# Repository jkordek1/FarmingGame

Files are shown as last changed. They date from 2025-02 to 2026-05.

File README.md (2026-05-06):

# FarmingGame


[]()



## About
<p align="center">
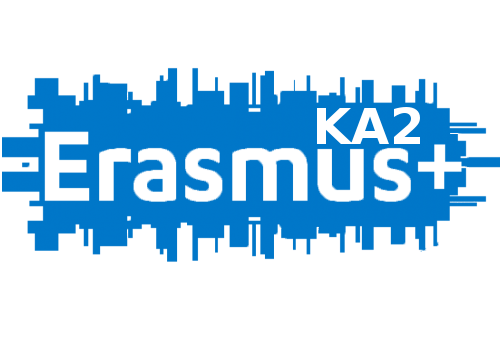
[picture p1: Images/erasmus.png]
  
</p>

This is an electronic board game about farming where 2-4 players compete to grow crops and score the most points. Players strategically plant crops with different growing times and point values, while dealing with unpredictable weather that affects crop growth. The game features three difficulty modes, each with unique weather mechanics and strategic depth.

**Key Features:**
- **Multiple difficulty modes**: Simple (beginner-friendly), Medium (balanced), and Advanced (strategic with crop-specific weather effects)
- **Dynamic weather system**: Weather drawn from a "bag" of 11 cards (4 Sunny, 3 Rain, 4 Drought) that refills when empty
- **Strategic depth**: Advanced mode includes stale crops (25% points if not harvested quickly) and planting limits (2 crops per turn)
- **Physical feedback**: LED ring shows field status, OLED displays for each player, central TFT screen with crop images
- **Sound and visual effects**: Weather animations, harvest celebrations, victory fanfare

## Project idea
The idea was to develop an electronic board game for 2-4 players that combines STEM with agriculture. It was funded by the Erasmus+ KA2 project [SEED2STEM: Planting the future of education](https://www.tvz.hr/introducing-seed2stem-planting-the-future-of-education/).

## How to Play

### Game Setup
1. **Power on** the device - "FARM GAME" logo appears
2. **Player 1** presses CONFIRM to start player selection (or hold BACK for settings)
3. **All players** press CONFIRM to join (2-4 players, 10-second window)
4. **Game begins** automatically when time expires or all slots filled

### Turn Structure
Each player's turn has three phases:

1. **Weather Phase**: Press CONFIRM to reveal weather → Check effects on your crops → Press CONFIRM to continue
2. **Field Management**: Navigate between fields (F1-F4) to harvest ready crops or plant new ones
3. **End Turn**: Navigate to "End Turn" and press CONFIRM twice (or hold FORWARD for quick skip)

### Controls
- **BACK/FORWARD**: Navigate left/right, decrease/increase values
- **CONFIRM**: Select, confirm actions
- **Hold FORWARD**: Quick jump to "End Turn" (1-second hold)

## Crops & Strategy

### Crop Information
| Crop | Turns to Grow | Simple Mode | Medium Mode | Advanced Mode |
|---|---|---|---|---|
| **Corn** 🌽 | 2 | 1 point | 2 points | 3 points |
| **Carrot** 🥕 | 3 | 4 points | 5 points | 6 points |
| **Tomato** 🍅 | 4 | 8 points | 9 points | 12 points |
| **Lettuce** 🥬 | 5 | 15 points | 16 points | 20 points |
| **Blueberry** 🫐 | 6 | 20 points | 25 points | 30 points |

### Game Modes

#### Simple Mode (Green) - Beginner Friendly
- **Weather effects**: Drought = no growth, Rain = 50% chance growth, Sun = normal growth
- **Strategy**: Focus on learning crop timing, weather is mostly unpredictable

#### Medium Mode (Yellow) - Balanced Challenge
- **Weather effects**: Drought = no growth, Rain = double growth, Sun = normal growth
- **Strategy**: Time plantings before rain for maximum benefit

#### Advanced Mode (Red) - Strategic Mastery
- **Crop-specific weather effects**: Each crop reacts differently to weather
  - **Drought**: Only corn survives (80% chance), others die
  - **Sun**: Corn & Tomato thrive (double growth), others normal
  - **Rain**: Carrot, Lettuce & Blueberry thrive (double growth), others normal
- **Stale crops**: Unharvested ready crops spoil and give only 25% points
- **Planting limit**: Maximum 2 crops per turn
- **Strategy**: Match crops to expected weather, harvest immediately when ready

### Weather System
Weather is drawn from a "bag" of 11 cards:
- **4 Sunny days** (36.4%)
- **3 Rainy days** (27.3%) 
- **4 Drought days** (36.4%)

When all cards are used, the bag refills and reshuffles. Players can track drawn weather to predict what's coming next!

## Project Status
- [x] Breadboard prototype
- [x] Schematic design
- [x] PCB design and manufacturing
- [x] Enclosure design and 3D printing
- [x] 3D CAD assembly and renders
- [x] Hardware assembly
- [x] Core game programming
- [x] **Game balancing completed** - All three difficulty modes fully implemented and balanced
- [x] **Weather system** - Sophisticated bag-based weather with crop-specific effects
- [x] **Advanced features** - Stale crops, planting limits, long-press shortcuts
- [x] **Audio/Visual polish** - Sound effects, animations, victory celebrations
- [x] **Documentation** - Complete rules, assembly instructions, cheat sheets
- [x] Final testing and optimization

## Current Game State
The game is **feature-complete and fully playable** with three balanced difficulty modes:
- **Simple Mode**: Perfect for beginners and casual play
- **Medium Mode**: Balanced challenge with predictable weather effects  
- **Advanced Mode**: Strategic depth with crop-weather matching, spoilage mechanics, and resource management

**Recent Major Updates:**
- Implemented crop-specific weather effects in Advanced mode
- Added stale crop mechanics (25% points penalty)
- Introduced per-turn planting limits (2 crops max in Advanced mode)
- Balanced weather bag system (4 Sun, 3 Rain, 4 Drought)
- Enhanced user interface with long-press shortcuts and improved text positioning
- Complete audio/visual feedback system

## Known Issues
- ~~Hardware is completely functional, software could use some extra work~~ ✅ **Resolved**
- ~~Due to ESP32 Neopixel library bug, the first WS2812B LED sometimes lights up green~~ ✅ **Fixed
- ~~Game balance needed adjustment~~ ✅ **Completed - all modes balanced**

**Current Status**: No major issues remaining. Game is stable and fully functional.

## Hardware & Display System

### Main Components
- **ESP32-S3 microcontroller** (Adafruit Feather ESP32-S3)
- **Central TFT display**: GC9A01 240x240 circular display showing crop images and game status
- **Player displays**: 4x SSD1306 128x64 OLED screens for individual player information
- **Status indicators**: WS2812B LED ring (16 LEDs, 4 per player) showing field status
- **Input system**: PCF8575 I/O expander with tactile buttons for each player
- **Audio feedback**: Buzzer for sound effects and music
- **Power management**: Optional MAX17048 battery fuel gauge
- **Connectivity**: Powered via USB-C

### Display System
- **Central TFT**: Shows active player (colored border), crop images, weather animations, victory screens
- **Individual OLEDs**: Personal scores, field information, menus, weather effects for each player
- **LED Ring**: Gray (empty field), colored (growing crop matching crop color), dark (player not active)
- **Audio**: Navigation beeps, weather sounds, harvest celebrations, victory fanfare

## 3D renders
Full1
Animation

## Images
IRL

## PCB
There is a donut-shaped circuit board containing a microcontroller, all SMD and THD components.

## Enclosure
The enclosure consists of three different sections: an upper orange section, a middle section and a lower section, both made of white PLA material. There are also three buttons in four different colors that are used for the menu controls. There is also a 3D printed part that represents four ground points for each player.

## Project folder structure
    ├── ...
    ├── Images                  # Images of the project
    ├── 3D models               # Enclosure model parts
    ├── KiCAD Files             # Main folder
    │   ├── FullPCB             # 3d models of components
    │       ├── BoardGame       # KiCAD project for main PCB
    └── ...

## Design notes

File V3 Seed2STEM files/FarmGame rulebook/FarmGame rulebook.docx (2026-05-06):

FarmGame rulebook

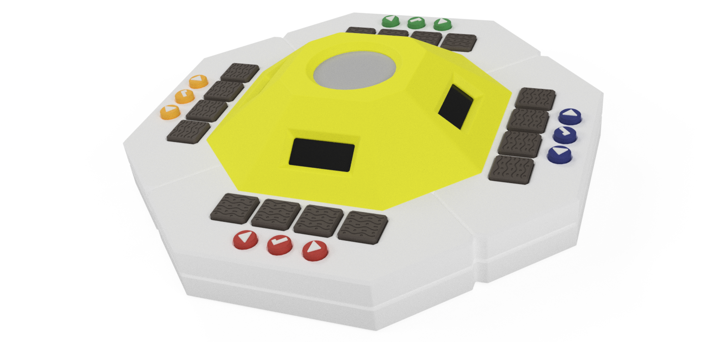
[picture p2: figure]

## Welcome to Farm Game!

Step into the boots of a farmer and compete with friends in this exciting agricultural challenge! You'll plant crops, manage unpredictable weather, and race to harvest at the perfect time to score the most points. Will you play it safe with quick-growing corn, or risk it all on precious blueberries?

## Getting Started

### Starting the Game

1. Turn on your device and watch the "FARM GAME" logo appear

2. Player 1 can either:

  - Press CONFIRM to go to player selection
  - Hold BACK for 2 seconds to access settings

### Player Selection (10 seconds)

- Each player presses CONFIRM to join the game
- You need at least 2 players to start (maximum 4)
- If there are not enough players, the game will continue waiting until more players join

## Controls and Display

### Your Controls

- BACK: Navigate left / Decrease value
- FORWARD: Navigate right / Increase value
- CONFIRM: Select / Confirm action

### Game Display

#### The Main Screen (Center)

Your central game view showing:

- Colored border: Shows whose turn it is
- Crop images: See what's growing in each field
- Field status: Empty fields, growing crops, or ready-to-harvest crops

#### Your Personal Screen (OLED)

Each player gets their own information display:

- Current score
- Field status and crop information
- Weather effects and menus
- Turn-specific information

#### Field Status Lights (LEDs)

16 colorful lights around the device showing everyone's field status:

- Gray lights: Empty fields
- Colored lights: Growing crops (each crop has its own color)
- Dark lights: Player not in the game

## Your Crops

Every crop has different growing times and point values. Some grow fast but give fewer points, others take longer but reward your patience!

Crop | Turns to Grow | Simple Mode | Medium Mode | Advanced Mode
Corn 🌽 | 2 turns | 1 point | 2 points | 3 points
Carrot 🥕 | 3 turns | 4 points | 5 points | 6 points
Tomato 🍅 | 4 turns | 8 points | 9 points | 12 points
Lettuce 🥬 | 5 turns | 15 points | 16 points | 20 points
Blueberry 🫐 | 6 turns | 20 points | 25 points | 30 points

### Crop Characteristics

- Corn: Quick and reliable, but modest points
- Carrot: Decent growing time with fair rewards
- Tomato: Takes patience but pays reasonably well
- Lettuce: Premium crop with good returns for the wait
- Blueberry: High maintenance and risky, but potentially the most rewarding!

## How to Play

### 1. Weather Phase ☀️🌧️🏜️

Every turn starts with checking the weather:

1. The active player presses CONFIRM to reveal the weather

2. Watch the weather animation on the main screen

3. Check your personal screen to see how the weather affects each of your crops:

  - Field number and crop name
  - Weather effect symbol (X, ?, +, ++, +++)

4. Press CONFIRM when ready to continue

Weather Types:

- Sunny ☀️: Generally good for crop growth
- Rain 🌧️: Some crops love it, others just get normal growth
- Drought 🏜️: Tough conditions - most crops struggle

### 2. Harvest and Plant Phase

Now you manage your 4 fields:

1. Use BACK/FORWARD to navigate between your fields (F1-F4) or "End Turn"

2. Quick tip: Hold FORWARD for 1 second to jump directly to "End Turn"

3. Press CONFIRM on any field to:

  - Empty field: Plant a new crop (if allowed)
  - Ready crop: Harvest and earn points
  - Growing crop: Nothing happens (you'll hear a beep)
  - End Turn: Confirm twice to finish your turn

When you harvest:

- Points appear in your player color
- Your score updates immediately
- The field becomes empty and ready for new crops

### 3. Planting Phase (when you select an empty field)

1. Browse available crops with BACK/FORWARD

2. Your screen shows the crop name, main screen shows turns and points

3. Press CONFIRM to plant the selected crop

4. Return to field management

### 4. End of Turn

- Weather effects are applied to all your growing crops
- Next player takes their turn
- Game continues until all rounds are complete

## Game Modes

Choose your difficulty level! Each mode offers different weather mechanics and point values.

### SIMPLE Mode - "Learning the Basics"

Weather Effects:

- Drought: No growth for any crops
- Rain: 50% chance each crop will grow (random)
- Sun: Normal growth for all crops

Best for: New players learning the game. Weather is unpredictable, so focus on understanding crop timing.

### MEDIUM Mode - "Balanced Challenge"

Weather Effects:

- Drought: No growth for any crops
- Rain: Double growth for all crops (-2 turns)
- Sun: Normal growth for all crops (-1 turn)

Best for: Players who want predictable weather patterns. Rain becomes very powerful for everyone.

### ADVANCED Mode - "Strategic Farming"

Weather Effects:
Each crop reacts differently to weather conditions:

Weather | Corn 🌽 | Carrot 🥕 | Tomato 🍅 | Lettuce 🥬 | Blueberry 🫐
Drought | 80% chance normal growth | No growth | No growth | No growth | No growth
Sun | Double growth (-2 turns) | Normal growth | Double growth (-2 turns) | Normal growth | Normal growth
Rain | Normal growth | Double growth (-2 turns) | Normal growth | Double growth (-2 turns) | Double growth (-2 turns)

Weather Effect Symbols:

- X = No growth / Stale crop
- ? = Chance-based growth (80% for corn in drought)
- + = Normal growth (-1 turn)
- ++ = Double growth (-2 turns)

Advanced Mode Special Rules:

Stale Crops:

- Crops left unharvested too long will spoil and lose value
- Stale crops show "STALE" in red and give only 25% points
- You must harvest quickly or watch your crops deteriorate!

Planting Limit:

- You can only plant 2 crops per turn (not total - per turn!)
- Your screen shows "Planted:X/2" to track your progress
- Empty fields show "X" when you've reached your limit
- Choose your plantings wisely each turn!

Best for: Experienced players who enjoy strategic depth. Match crops to expected weather, harvest quickly to avoid spoilage, and plan your limited plantings carefully.

## Settings Menu

### Accessing Settings

From the start screen, Player 1 holds BACK for 2 seconds to enter the settings menu.

### Available Settings

#### 1. LED Brightness

- Options: 0%, 25%, 50%, 75%, 100%
- Default: 50%
- What it does: Adjusts how bright the status lights shine
- The lights turn on when you enter this setting

#### 2. Number of Rounds

- Options: 5, 10, 15, or 20 rounds
- Default: 10 rounds
- What it does: Sets how many turns each player gets

#### 3. Menu Sounds

- Options: ON / OFF
- Default: ON
- What it does: Toggle the helpful beeps and navigation sounds

#### 4. Battery Info

- Display: Shows battery voltage and remaining power
- What it does: Monitors your device's power supply (if battery sensor is connected)
- Color coding: Green (good), Orange (low), Red (very low)
- Note: Information only - you can't change this setting

#### 5. Weather System

- Options: SIMPLE / MEDIUM / ADVANCED
- Default: SIMPLE
- What it does: Changes how weather affects crops and determines point values

#### 6. Exit Settings

- Action: Saves all settings and returns to player selection
- Your settings are remembered when you power off the device

### Using Settings

- BACK/FORWARD: Navigate between settings
- CONFIRM: Enter adjustment mode
- While adjusting:
  - BACK/FORWARD: Change the value
  - CONFIRM: Save and exit adjustment mode

## Winning the Game

### Scoring

Your score increases each time you harvest a ready crop. Point values depend on the crop type and which game mode you're playing (see the crop table above).

### Game End

- The game ends after everyone completes their set number of rounds
- Victory music plays (a triumphant C-E-G-C fanfare)
- The winner's status lights pulse three times in celebration
- The player with the highest score wins
- If there's a tie: Multiple winners share the victory with "TIE!" displayed

Victory Screen:

- Main Screen: Shows the winner's name with their color, plus complete rankings of all players
- Winner's Screen:
  - Displays "YOU WON!" or "TIED!" in the center
  - Shows "Press CONFIRM" to start a new game
  - Only winners can start the next game
- Other Players' Screens:
  - Shows their final ranking and total score
  - Must wait for the winner to decide on starting a new game

## Tips & Strategy

### General Strategy

1. Quick crops (like corn) are safe bets but give fewer points

2. Slow crops (like blueberries) are risky investments but can pay off big

3. Keep an eye on weather patterns - they come from a limited "bag" of possibilities

4. Don't put all your eggs in one basket - diversify your fields

### Understanding Weather Patterns

Weather isn't completely random! It comes from a "weather bag" containing:

- 4 Sunny days
- 3 Rainy days
- 4 Drought days

Once all 11 weather cards are used, the bag refills. Smart players track what's been drawn to predict what's coming next!

### Mode-Specific Tips

Simple Mode:

- Focus on learning crop timing rather than weather prediction
- Plant a mix of fast and slow crops to spread your risk
- Weather is mostly unpredictable, so don't rely on it too much

Medium Mode:

- Plant slower crops before expected rain for maximum benefit
- Rain helps everyone equally, so timing is everything
- Drought is your enemy - harvest quickly when you see it coming

Advanced Mode:

- Match crops to weather:
  - Plant corn before sun or drought (it's tough and loves sun)
  - Plant tomatoes before sunny weather
  - Plant carrots and lettuce before rain
  - Plant blueberries before rain (they love it - 30 points!)
- Harvest immediately when crops are ready - spoilage costs you 75% of your points!
- Plan your 2 plantings per turn carefully - prioritize high-value crops
- Track the weather bag - with 4 droughts, 3 rains, and 4 sunny days, drought is most common

### Field Management

- Keep crops at different growth stages so you always have something ready
- Never leave all fields empty (unless you've hit your planting limit in Advanced mode)
- In Advanced mode, sometimes harvesting is more important than planting
- Time-saving tip: Hold FORWARD for 1 second to quickly jump to "End Turn"

## Player Colors

- Player 1: Red
- Player 2: Yellow
- Player 3: Green
- Player 4: Blue

## Ready to Play?

Now you know everything you need to become a farming champion! Start with Simple mode to learn the basics, then challenge yourself with Medium and Advanced modes.

Whether you're growing reliable corn or precious blueberries, every choice matters. Good luck, and may the best farmer win! 🌾

## Technical Information

### Hardware Requirements

- ESP32-S3 microcontroller
- GC9A01 240x240 TFT display
- 4x SSD1306 128x64 OLED displays
- WS2812B LED ring (16 LEDs)
- PCF8575 I/O expander for buttons
- MAX17048 battery fuel gauge (optional)
- Buzzer for sound effects

### Display Layouts

TFT Screen:

- Colored ring showing active player
- Center area: crop images, field status, weather
- Score display during status updates

OLED Screens:

- Player-specific information
- Field selection menus
- Crop selection menus
- Weather effects summary
- Turn status

## Troubleshooting

### Game Won't Start

- Ensure at least 2 players press CONFIRM during player selection
- Check that all displays are connected

### No Sound

- Check Menu Sounds setting (may be OFF)
- Verify buzzer connection

### Battery Shows "Sensor not found"

- MAX17048 sensor not detected or not connected
- Game still playable without battery monitoring

### LEDs Not Working

- Check LED Brightness setting (may be 0%)
- Verify LED ring connection

## Credits

Farm Game - A competitive multiplayer farming experience with strategic weather mechanics and crop management.

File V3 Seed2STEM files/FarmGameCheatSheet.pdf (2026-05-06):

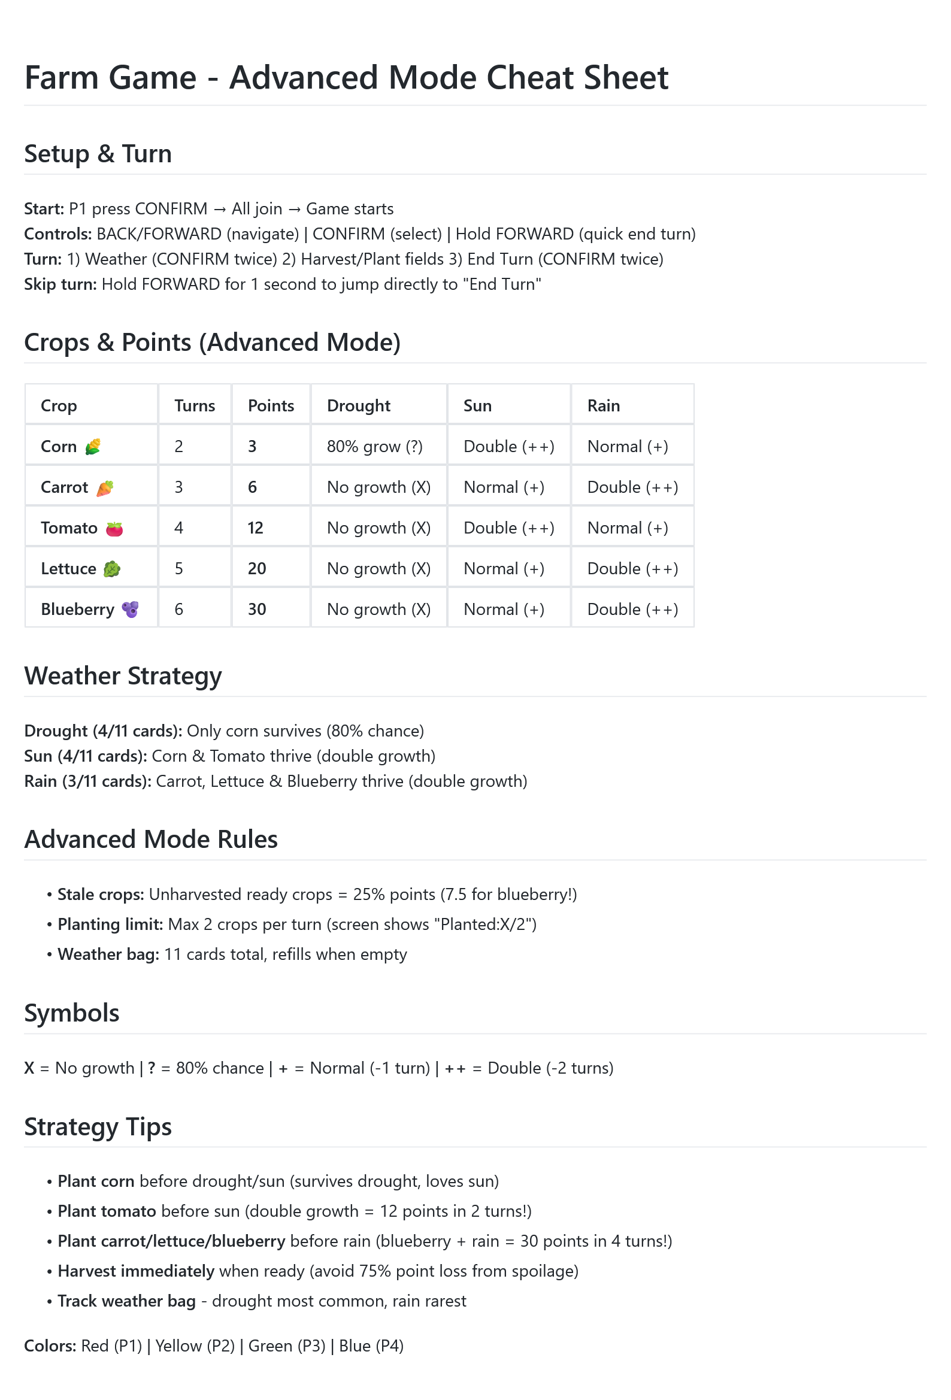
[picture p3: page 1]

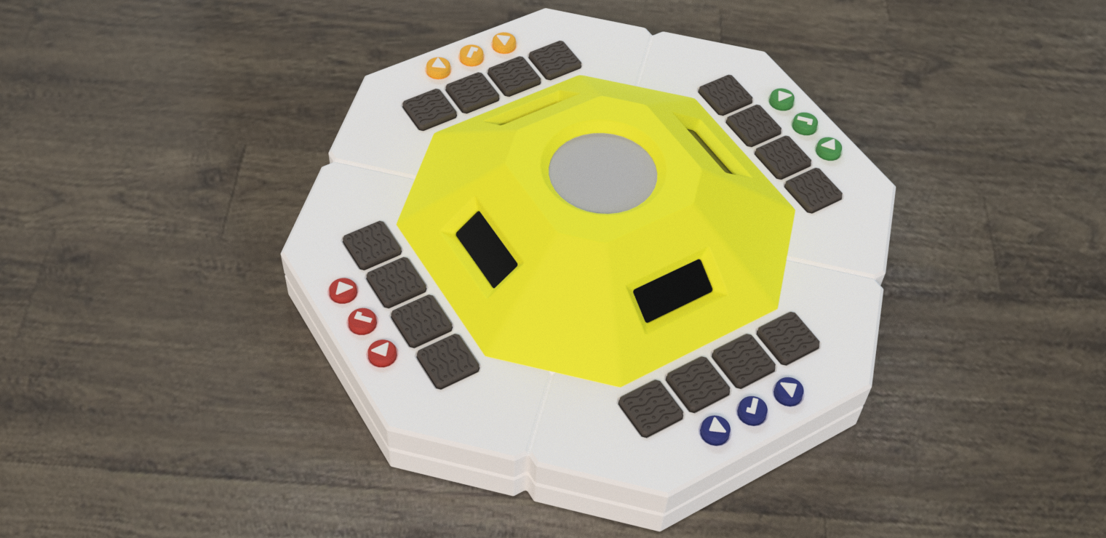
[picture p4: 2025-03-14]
Images/Full1.png

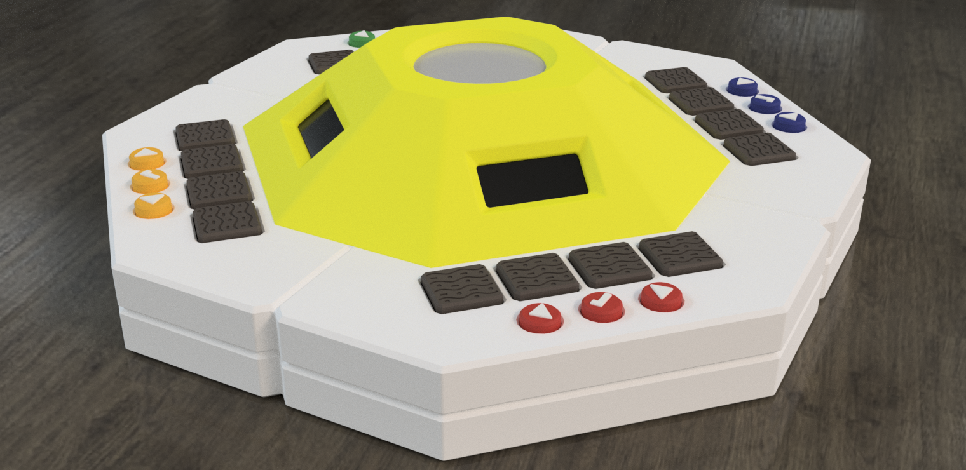
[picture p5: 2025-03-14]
Images/Full2.png

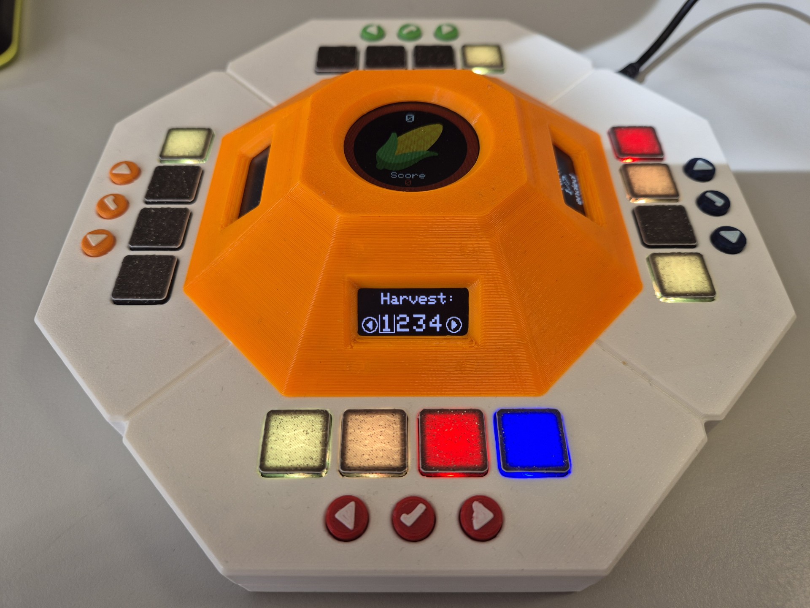
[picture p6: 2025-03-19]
Images/IRL.jpg

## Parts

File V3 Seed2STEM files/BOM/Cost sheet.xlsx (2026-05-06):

Name | # of pieces per device | # of pieces for 10 devices | Cost for 10 devices [€] | Supplier
PCB with pre-assembled SMT components | 1 | 10 | 70.00 | JLCPCB
Power switch | 1 | 10 | 15.00 | Digikey (https://www.digikey.com/en/products/detail/zf-electronics/PRK22J5BBBNN/1083857)
Speaker | 1 | 10 | 2.10 | TME (https://www.tme.eu/hr/en/details/ld-bzen-1205/electromagnetic-sounders-w-o-generator/loudity/)
Port expander | 1 | 10 | 50.00 | Adafruit (https://www.adafruit.com/product/5611)
Battery | 1 | 10 | 75.00 | soldered (https://soldered.com/products/li-ion-battery-1200mah-3-7v?variant=62540928516445)
ESP32 microcontroller | 1 | 10 | 150.00 | Adafruit (https://www.adafruit.com/product/5885)
Push button | 12 | 120 | 7.94 | TME (https://www.tme.eu/hr/en/details/tact-64k-f/microswitches-tact/ninigi/)
Pin strip | 1 | 10 | 1.34 | TME (https://www.tme.eu/hr/en/details/ph1rb-40-ua/pin-headers/adam-tech/)
OLED cables 10cm | 5 | 50 | 47.50 | soldered (https://soldered.com/product/easyc-cable/)
GC9A01 cables | 8 | 80 | 7.00 | soldered (https://soldered.com/hr/proizvod/set-kablica-zensko-zenski-40-komada/)
M3 inserts | 16 | 160 | 27.52 | TME (https://www.tme.eu/hr/en/details/kvt-117m3/threaded-insertions/tappex/117m3/)
M2.5 inserts | 36 | 360 | 54.00 | TME (https://www.tme.eu/hr/en/details/kvt-002m2/threaded-insertions/tappex/002m2/)
M3 screws | 16 | 160 | 4.21 | TME (https://www.tme.eu/hr/en/details/b3x8_bn16/bolts/bossard/1017985/)
M2.5 screws | 36 | 360 | 10.33 | TME (https://www.tme.eu/hr/en/details/b2x5_bn2724/screws/bossard/5001676/)
GC9A01 display | 1 | 10 | 15.60 | aliexpress (https://www.aliexpress.com/item/1005007702290129.html?curPageLogUid=5H3M1Fq1tWO2)
OLED displays | 4 | 40 | 398.00 | soldered (https://soldered.com/product/display-oled-i2c-white-0-96-ssd1306/)
Bottom 3D printed part | 1 | 10 | 0.00 | -
Middle 3D printed part | 1 | 10 | 0.00 | -
Top 3D printed part | 1 | 10 | 0.00 | -
Field 3D printed part | 4 | 40 | 0.00 | -
Left/right button 3D printed part | 8 | 80 | 0.00 | -
Rubber feet | 8 | 80 | 0.00
Confirm 3D printed part | 4 | 40 | 0.00 | -
 |  |  | 935.54
 |  | Cost per device: | 93.5542 | (3D printed parts not included)

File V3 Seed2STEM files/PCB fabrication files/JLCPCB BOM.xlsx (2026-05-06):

Comment | Designator | Quantity | Footprint | LCSC Part #
WS2812B | D1, D10, D11, D12, D13, D14, D15, D16, D2, D3, D4, D5, D6, D7, D8, D9 | 16 | SMD5050-4P | C2874885
Resistor 220R | R1 | 1 | 0805 | C17557
Resistor 10k | R2, R13, R14, R15, R10, R11, R12, R7, R8, R9, R16, R17, R18 | 13 | 0805 | C17414
SMD Connector | J2 | 1 | SMD,P=1mm | C371510
Resistor 680R | R3, R6 | 2 | 0805 | C17798
Transistor NPN | Q1, Q2 | 2 | SOT-23 | C8512
MOSFET | Q3 | 1 | SOT-23 | C15127

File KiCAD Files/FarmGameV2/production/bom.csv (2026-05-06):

Designator | Footprint | Quantity | Value | LCSC Part #
BZ1 | Buzzer_TDK_PS1240P02BT_D12.2mm_H6.5mm | 1 | Buzzer
D1, D10, D11, D12, D13, D14, D15, D16, D2, D3, D4, D5, D6, D7, D8, D9 | LED_WS2812B_PLCC4_5.0x5.0mm_P3.2mm | 16 | WS2812B
J2 | JST_SH_SM04B-SRSS-TB_1x04-1MP_P1.00mm | 1 | OLED3&4
J5 | PinHeader_1x08_P2.54mm_Horizontal | 1 | Conn_01x08
Q1, Q2 | SOT-23 | 2 | MMBT2222A
Q3 | SOT-23 | 1 | AO3401A
R1 | 0805 | 1 | 220R
R10, R11, R12, R13, R14, R15, R16, R17, R18, R2, R7, R8, R9 | 0805 | 13 | 10k
R3, R6 | 0805 | 2 | 680R
SW1, SW10, SW11, SW12, SW2, SW3, SW4, SW5, SW6, SW7, SW8, SW9 | SW_PUSH_6mm | 12 | SW_Push_Dual
SW13 | Switch | 1 | POWER
U2 | ESP32-S3 | 1 | ~
U3 | PCF8575 | 1 | PCF8575

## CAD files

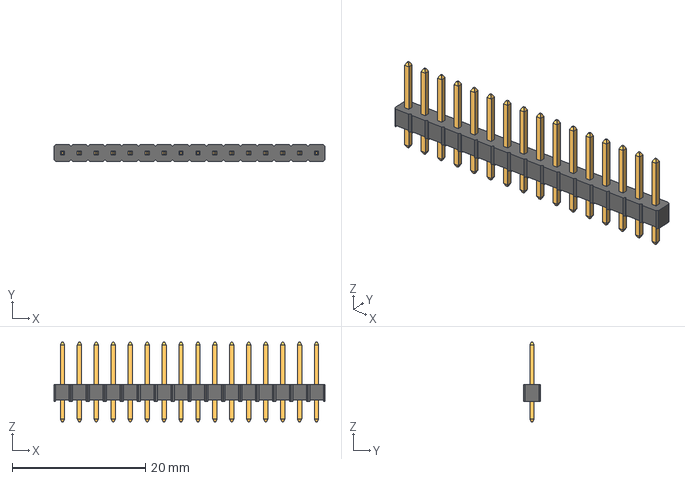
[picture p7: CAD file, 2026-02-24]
KiCAD Files/FarmGameV2/3DMODELS/16-Pin Header - Male - 2.54mm.step
40.6 x 2.54 x 11.9 mm

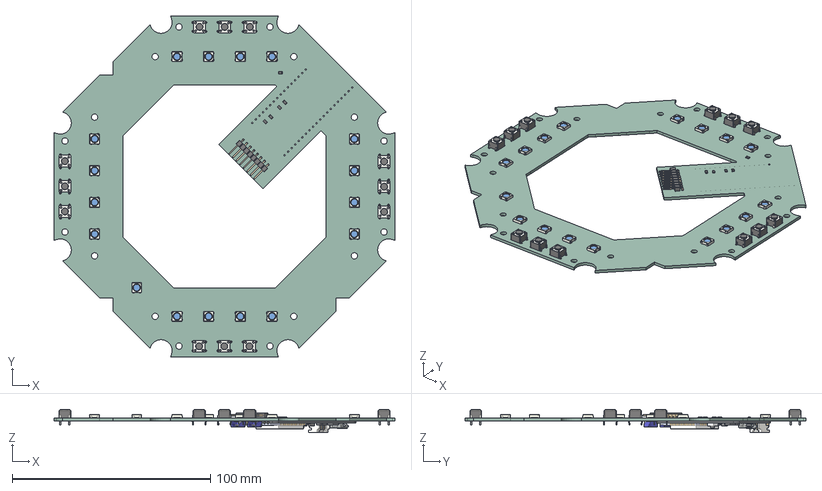
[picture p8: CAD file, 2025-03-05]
KiCAD Files/FarmGameV2/FarmGameV2.step
172.1 x 172.1 x 11.8 mm
LED_WS2812B_PLCC4_5.0x5.0mm_P3.2mm x 17
R_0805_2012Metric x 5
SW_PUSH_6mm x 12
PinHeader_1x08_P2.54mm_Horizontal
ESP32-WROVER v1
shield
JST PH M2P SMD v1
SM04B-SRSS-TB x 2
FullPCB_PCB

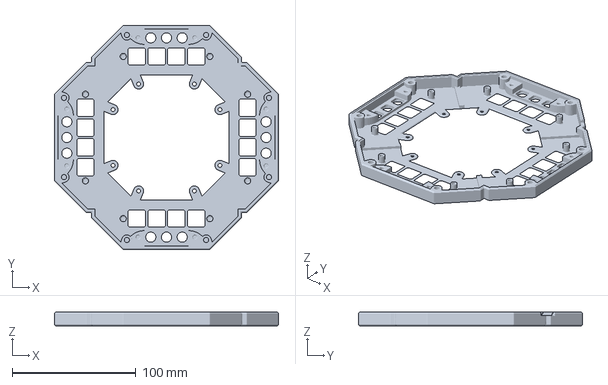
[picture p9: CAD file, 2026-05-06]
V3 Seed2STEM files/Enclosure 3D models/3MF/MiddleBodyPart.3mf
181.1 x 181.1 x 11.0 mm

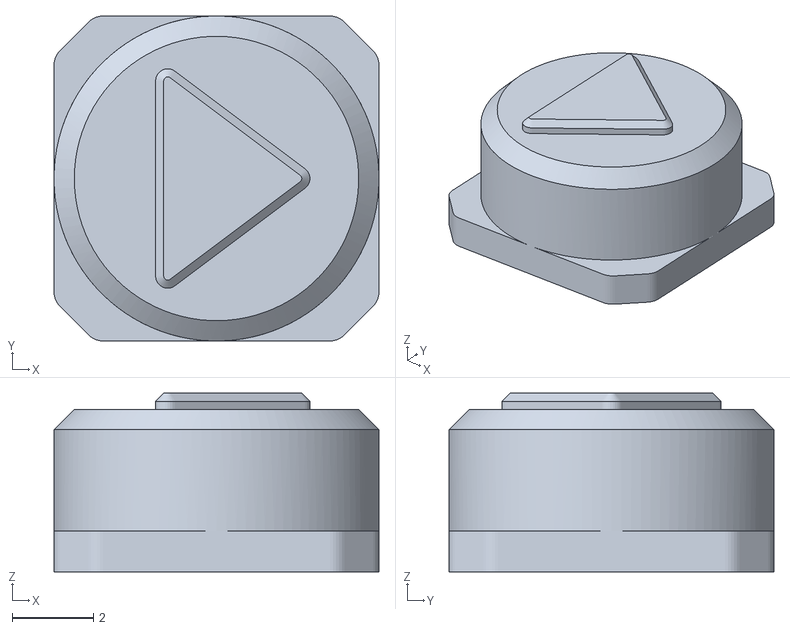
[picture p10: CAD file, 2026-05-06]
V3 Seed2STEM files/Enclosure 3D models/STL/Button - LeftRight.stl
8.00 x 8.00 x 4.40

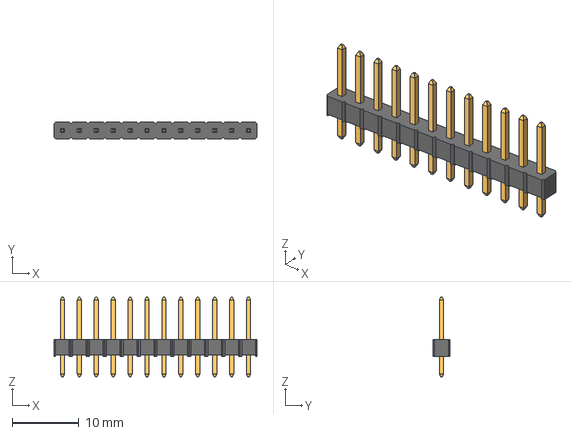
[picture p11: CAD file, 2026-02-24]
KiCAD Files/FarmGameV2/3DMODELS/12-Pin Header - Male - 2.54mm.step
30.5 x 2.54 x 11.9 mm

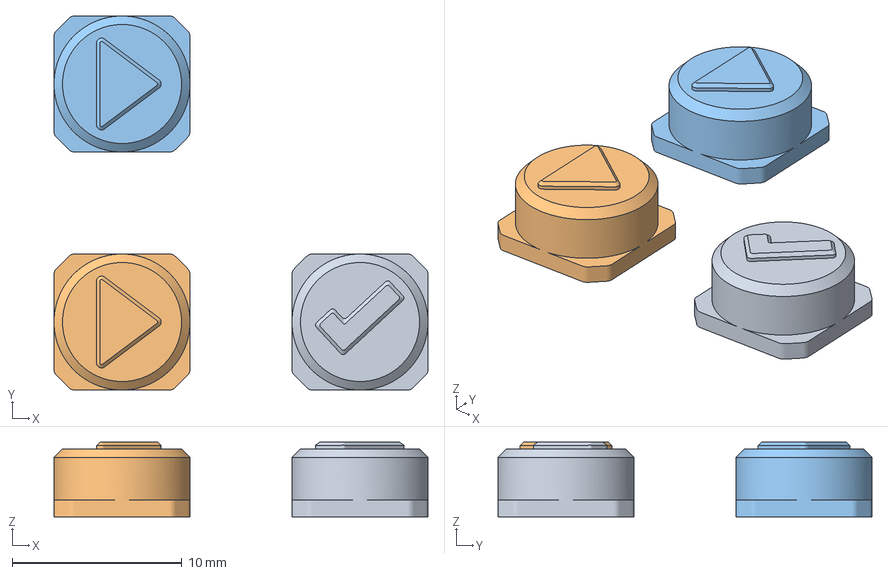
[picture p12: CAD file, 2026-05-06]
V3 Seed2STEM files/Enclosure 3D models/3MF/Buttons.3mf
22.0 x 22.0 x 4.40 mm
Button - Confirm.stl
Button - LeftRight.stl x 2

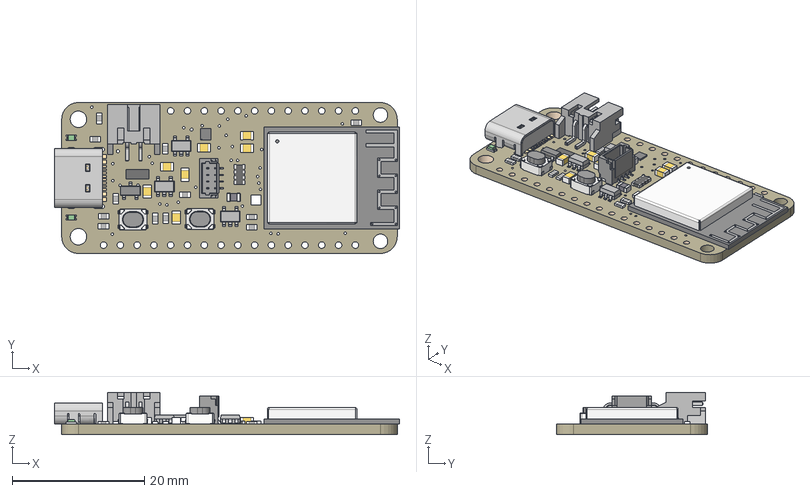
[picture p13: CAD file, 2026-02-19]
KiCAD Files/FarmGameV2/3DMODELS/Feather ESP32-S3.step
52.2 x 22.9 x 6.37 mm
Board
10uF x 7
AP2112/RT9080-3.3 x 3
MBR540
JSTPH
RED x 2
1uF x 12
KMR2 x 2
DMG3415U
USB C
ESP32-S3-MINI-1
LC709203F/MH
JST SH
WS2812B_SK6805_1515
10uF_1
10K

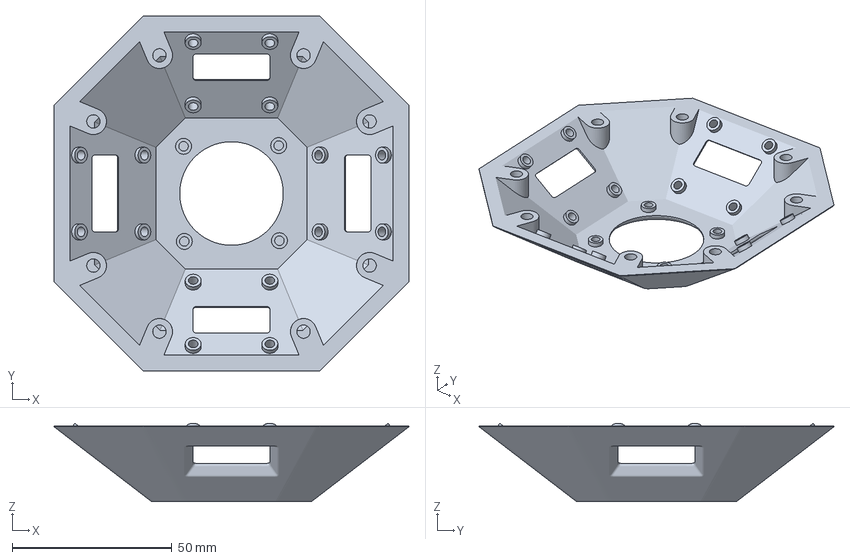
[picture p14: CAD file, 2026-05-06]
V3 Seed2STEM files/Enclosure 3D models/3MF/UpperBodyPart.3mf
111.1 x 111.1 x 24.5 mm

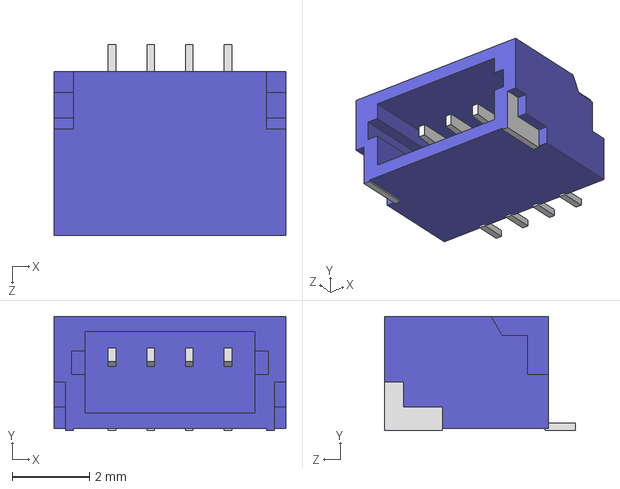
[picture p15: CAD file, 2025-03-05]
KiCAD Files/FarmGameV2/3DMODELS/SM04B-SRSS-TB.STEP
6.00 x 2.96 x 4.95 mm

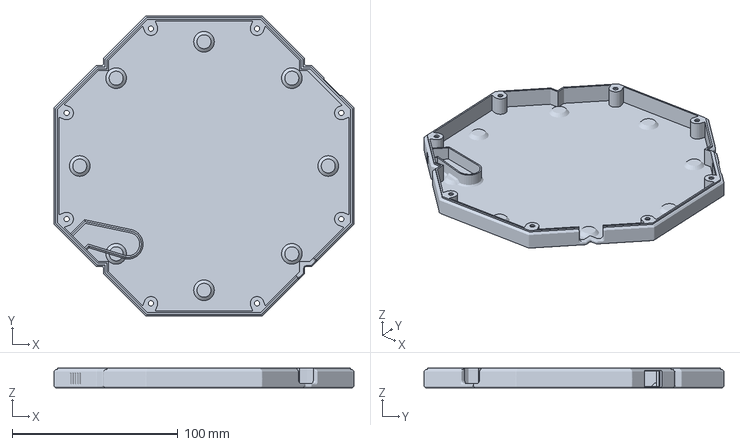
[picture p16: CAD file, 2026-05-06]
V3 Seed2STEM files/Enclosure 3D models/3MF/BottomBodyPart.3mf
181.1 x 181.1 x 12.0 mm

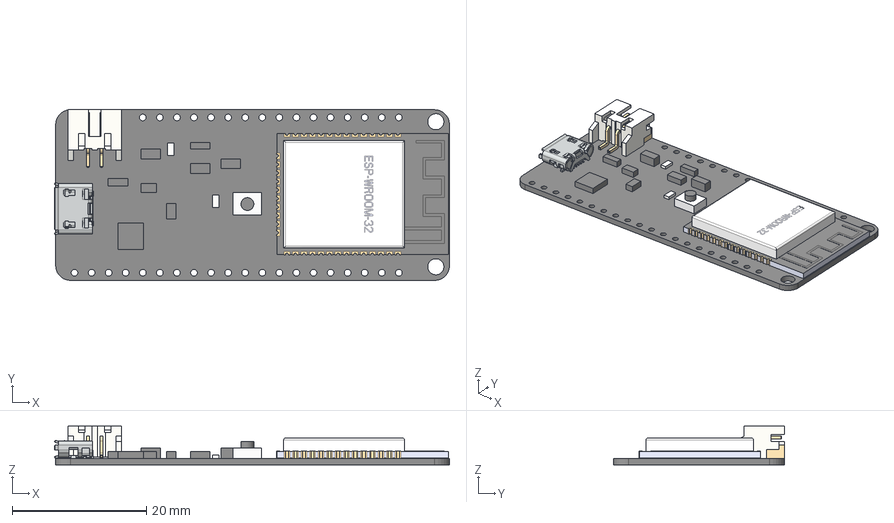
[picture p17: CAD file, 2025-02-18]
KiCAD Files/FarmGameV2/3DMODELS/Lolin32+V1.0.0 v2.step
58.8 x 25.4 x 5.80 mm
ESP32-WROVER
shield
JST PH M2P SMD

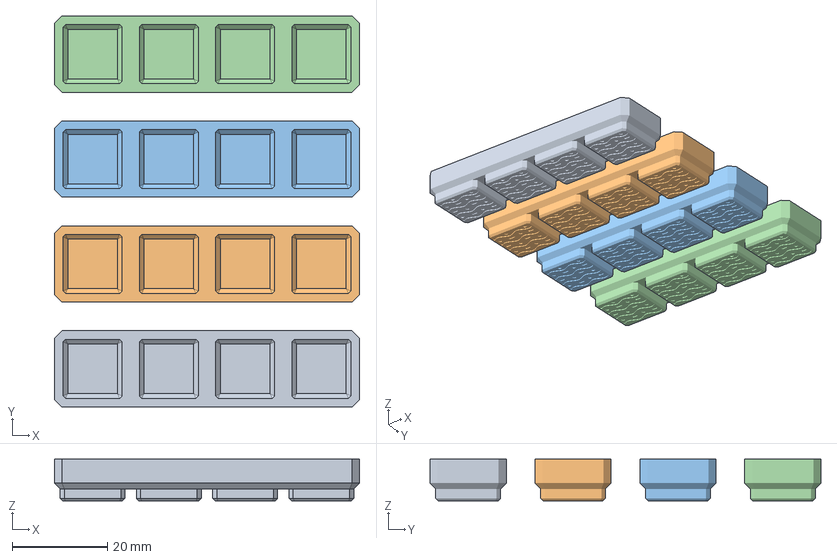
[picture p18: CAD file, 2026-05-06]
V3 Seed2STEM files/Enclosure 3D models/3MF/Field.3mf
64.0 x 82.0 x 8.75 mm
Field.stl x 4

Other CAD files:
V3 Seed2STEM files/Enclosure 3D models/STL/Button - Confirm.stl
V3 Seed2STEM files/Enclosure 3D models/STL/BottomBodyPart.stl
V3 Seed2STEM files/Enclosure 3D models/STL/Field.stl
V3 Seed2STEM files/Enclosure 3D models/STL/MiddleBodyPart.stl
V3 Seed2STEM files/Enclosure 3D models/STL/UpperBodyPart.stl

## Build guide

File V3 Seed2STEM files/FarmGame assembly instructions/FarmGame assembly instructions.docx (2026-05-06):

FarmGame assembly instructions

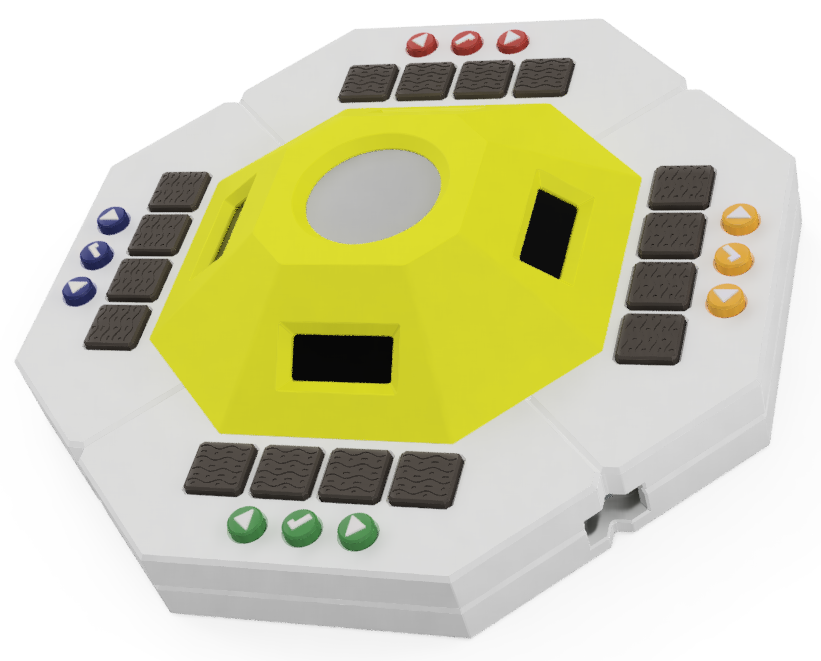
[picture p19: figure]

1. Ordering the printed circuit board (PCB) from manufacturer

Every FarmGame device has single PCB which contains most of the electronic components. Surface mount (SMT) components are hard to solder so it is required for the manufacturer to assemble the PCBs. Luckily, JLCPCB is a fast, reliable and cheap manufacturer which can do just that but we are not limited to their service, any other manufacturer will do since there are production files available. You can find the gerber files, BOM (Bill of materials) and CPL (Component placement list) in the PCB fabrication folder.

That said, go to jlcpcb.com and create a new quote. Click „add a gerber file“ and select the gerber.zip. Choose PCB quantity 5. On the bottom of the page, enable „PCB assembly“ and select Standard PCBA Type. This feature will enable you to assemble both PCB sides so select the Both Sides as Assembly Side.

Click Next and on the next screen you will see Top and Bottom sides of PCB. Click Next again. Now you will need to upload the BOM and CPL files from the PCB fabrication folder. After that click Process BOM&CPL. Check for errors and click Next. Check for component placement and orientation and click Next to proceed with the quote and finish with the payment process.

2. Ordering the rest of the electronical and mechanical components

In the BOM folder you can find the Cost Sheet with complete list of the all parts needed for the FarmGame. The last column contains supplier names and direct links to the catalog on their websites. Choose the required quantity and order all of them.

3. 3D printing the parts of enclosure

There are multiple 3D printed parts needed in order to assemble the FarmGame. All the files are available in the 3MF folder. Open the files using your printers slicing software. Here are some guidelines for 3D printing the models for each part of the FarmGame:

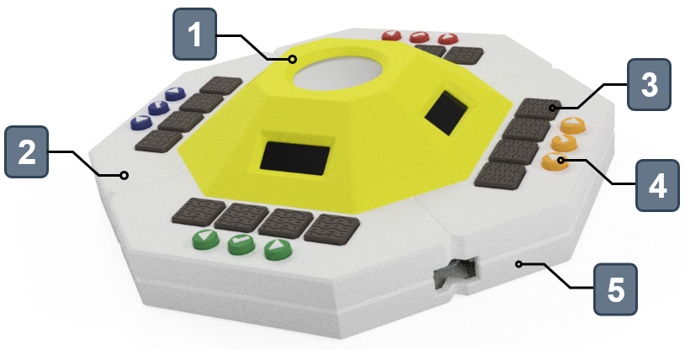
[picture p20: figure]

1. Upper body part
- Use yellow PLA material
- Use default settings in .3mf file
- Print on textured plate
- Remove support material
2. Middle body part
- Use white PLA material
- Use default settings in .3mf file
- Print on textured plate
3. Field
- Start printing with GalaxyBlack or similiar PLA material
- When printer pauses for color change use white PLA material
- End print with the same material which you started with
- Use default settings in .3mf file
- Print on textured plate
- Remove support material
4. Buttons
- Print 4 different sets of buttons using different colored (red, blue, yellow and green) PLA materials
- When printer pauses for color change use white PLA material
- Print on smooth plate
5. Bottom body part
- Use white PLA material
- Use default settings in .3mf file
- Print on textured plate
- Remove support material
4. Soldering

Tools and parts:

- 1x PCB with presoldered SMD components
- 12x Push buttons
- 1x Pin strip
- 1x ESP32 microcontroller
- 1x Speaker
- 1x Port expander
- Soldering iron

This part requires some soldering skills in order to solder the push buttons, pin strip and ESP32 microcontroller. Pay attention to which side you need to solder the components on. The push buttons (SW1 – SW12) and pin strip (J5) need to be placed from top side (soldered from the bottom side) – it's the side where the LEDs are soldered on.

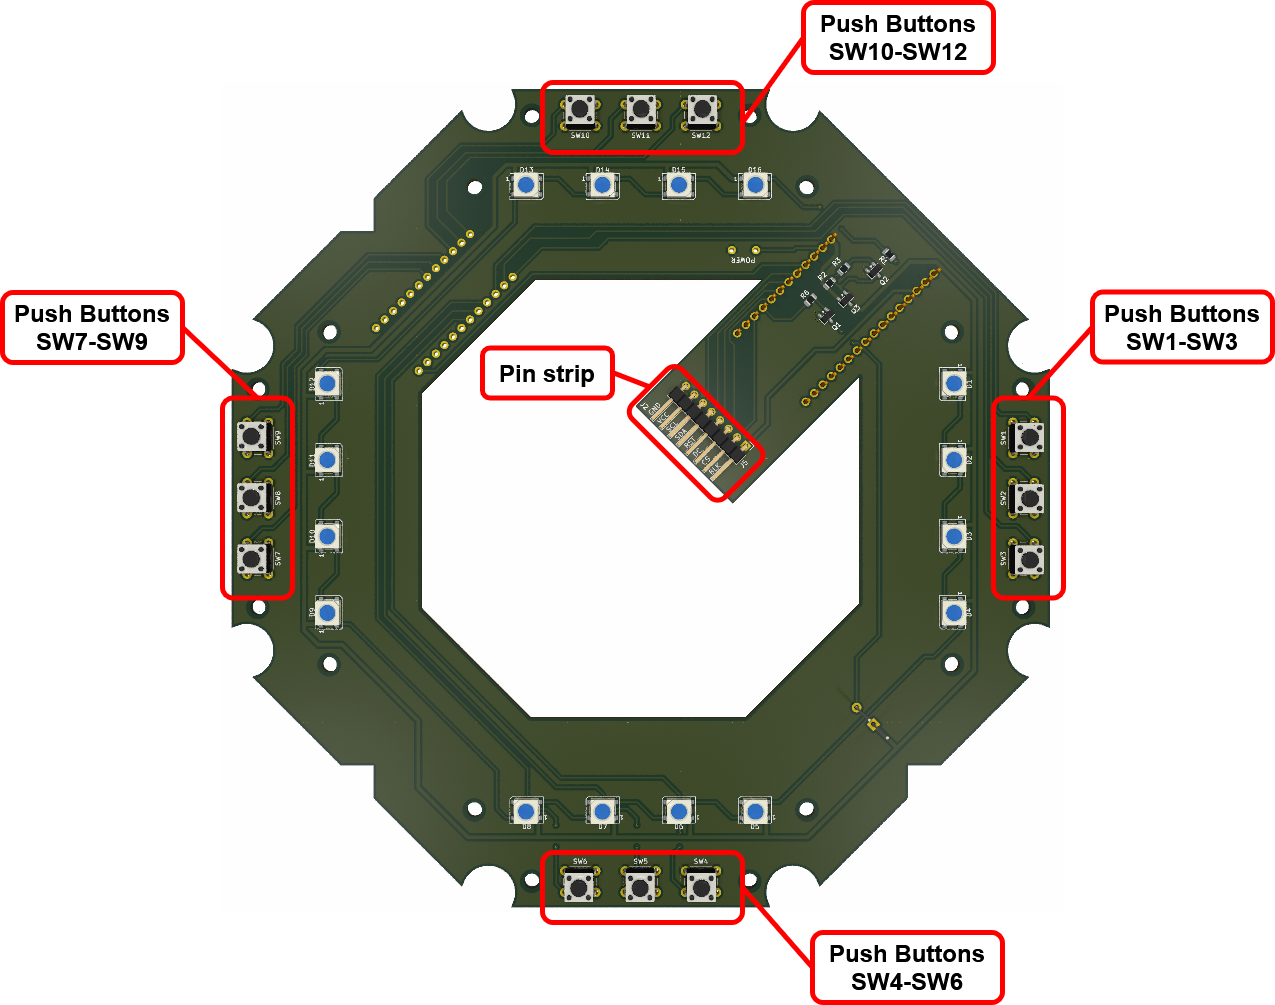
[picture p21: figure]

The ESP32 microcontroller, speaker, and port expander must be placed and soldered on the bottom side of the board, the same side as connector J2. The port expander must be oriented in a way that its VIN pin aligns with the hole marked by the white dot.

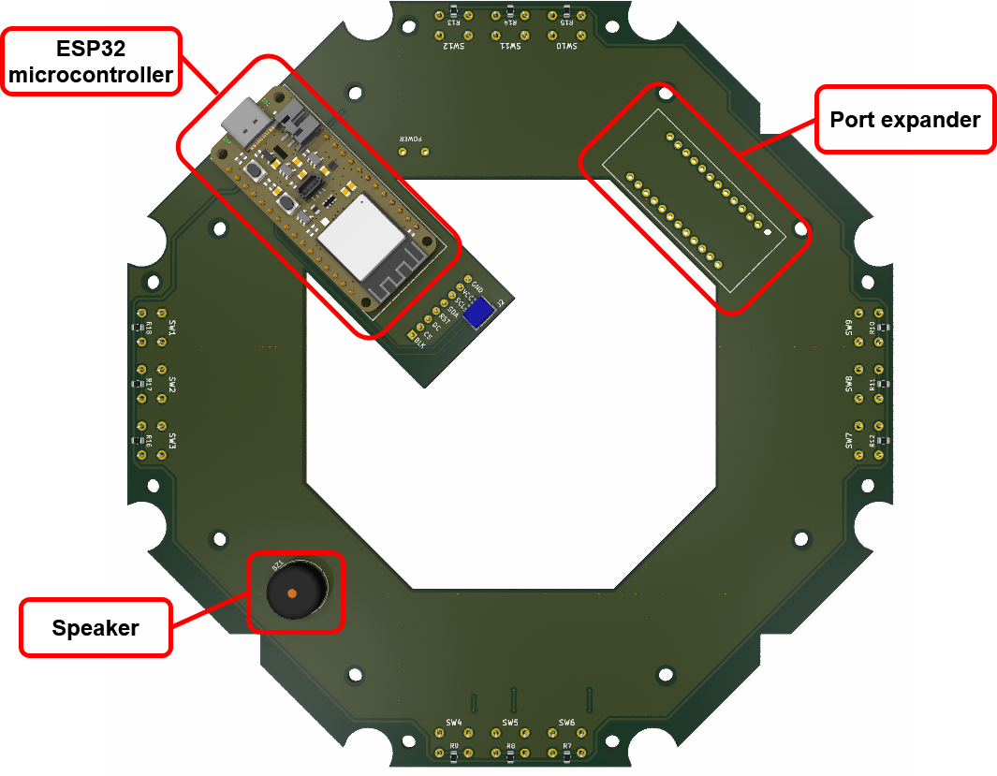
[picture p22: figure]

5. Installing brass threaded inserts

Tools and parts:

- 36x M2 threaded inserts
- 16x M3 threaded inserts
- Upper body part
- Middle body part
- Soldering iron

Before using screws, the brass threaded inserts must be installed. This is done using the soldering iron, set to a maximum tip temperature of 200 °C. Two sizes of brass inserts are required: M2 and M3. The size difference is obvious—the smaller inserts are M2, and the larger ones are M3. Be careful not to mix them up.

The Upper body part requires 20 M2 inserts marked with blue and 8 M3 inserts marked with red color:

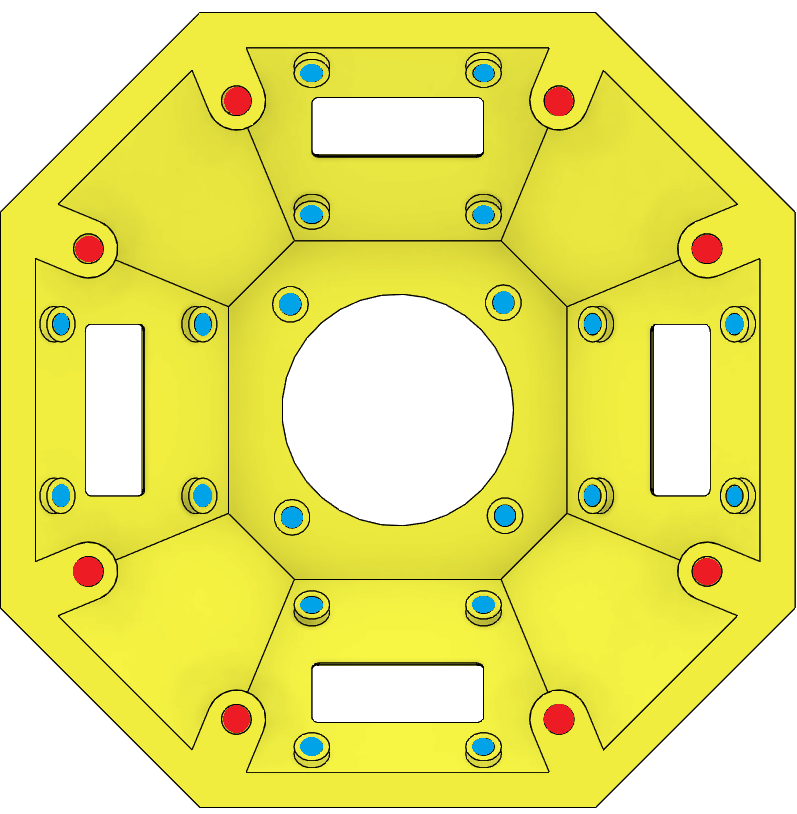
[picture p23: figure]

The Middle body part needs 16 M2 inserts marked with blue and 8 M3 inserts marked with red color pressed in using soldering iron:

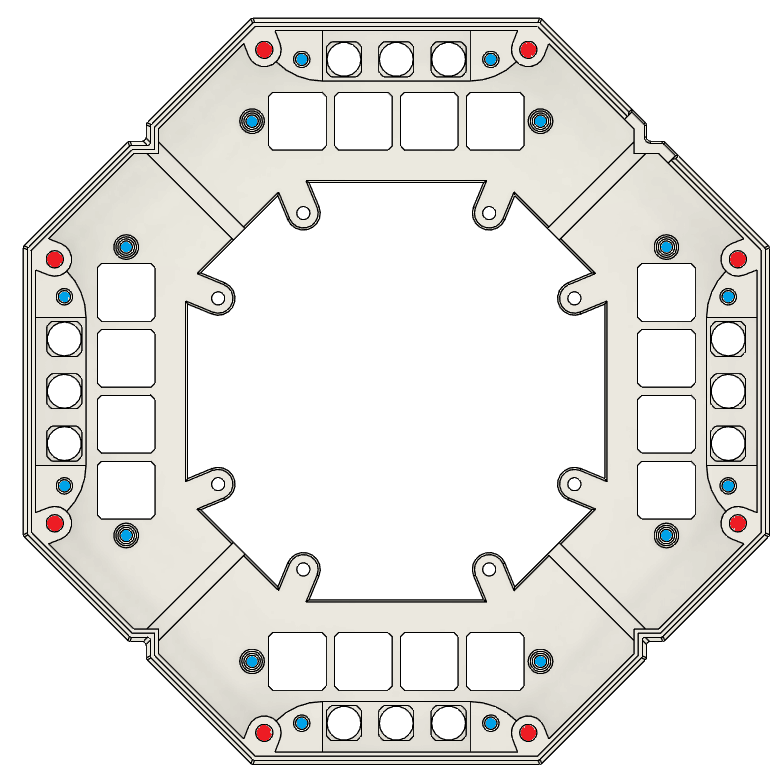
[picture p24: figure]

6. OLED display jumpers

Parts and tools:

- 2x OLED display
- Soldering iron

Every FarmGame device uses four different OLED displays. To get them to work properly, on two of them the jumper marked as JP6 needs to be shorted using the soldering iron. It should look something like this (notice the yellow arrow indicating the jumper):

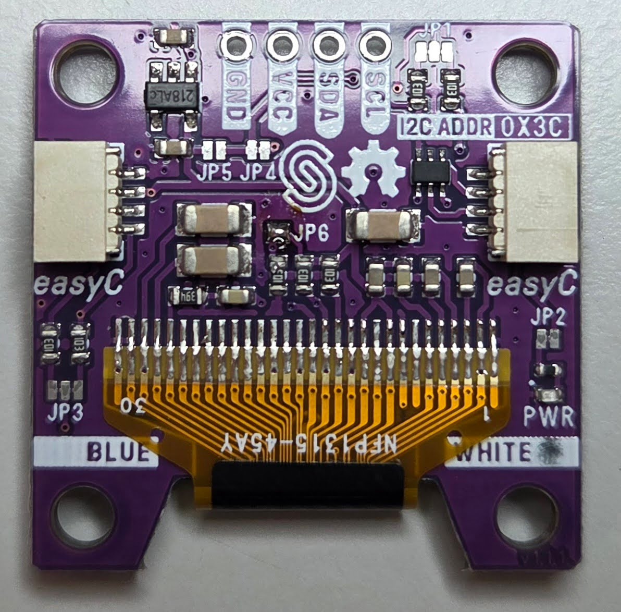
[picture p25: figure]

7. Upper body part assembly

Parts and tools:

- 20x M2 screws
- 4x OLED display
- 1x GC9A01 display
- Upper body part
- Screwdriver

Two OLED displays with jumpers JP6 shorted need to be mounted in orientation and spots indicated with yellow arrows:

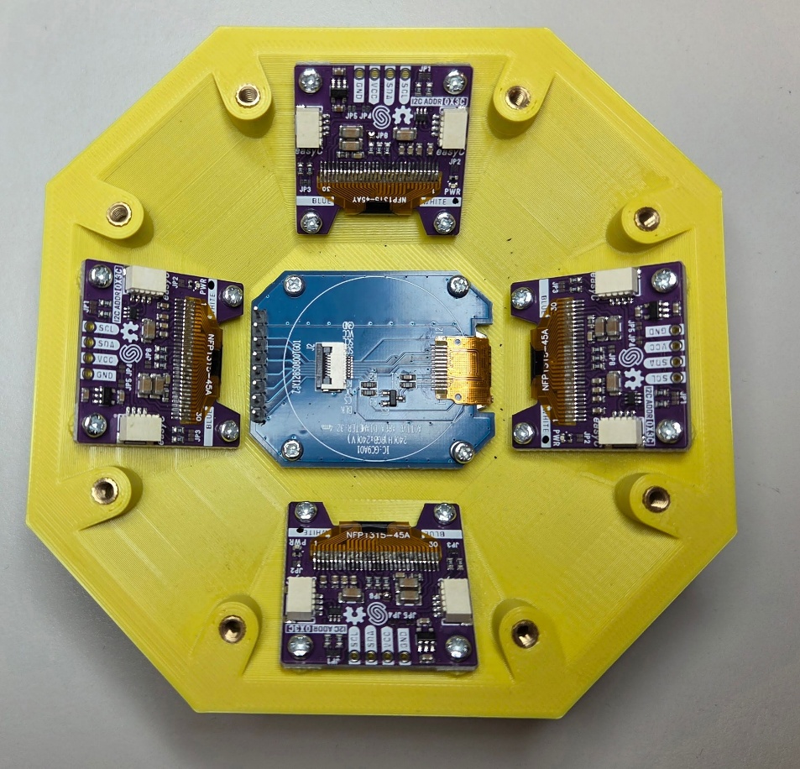
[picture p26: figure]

Mount the other two OLED displays and GC9A01 circular display as shown in previous image using the M2 screws (blue arrows). Don't tighten them up to much because there is a risk to crack their screens.

8. Wiring displays

Parts and tools:

- 4x 10cm 4-wire OLED cables
- GC9A01 cables (8x female to female jumper cables)

Use the two 10cm 4-wire OLED cables and connect two and two displays according to the following image:

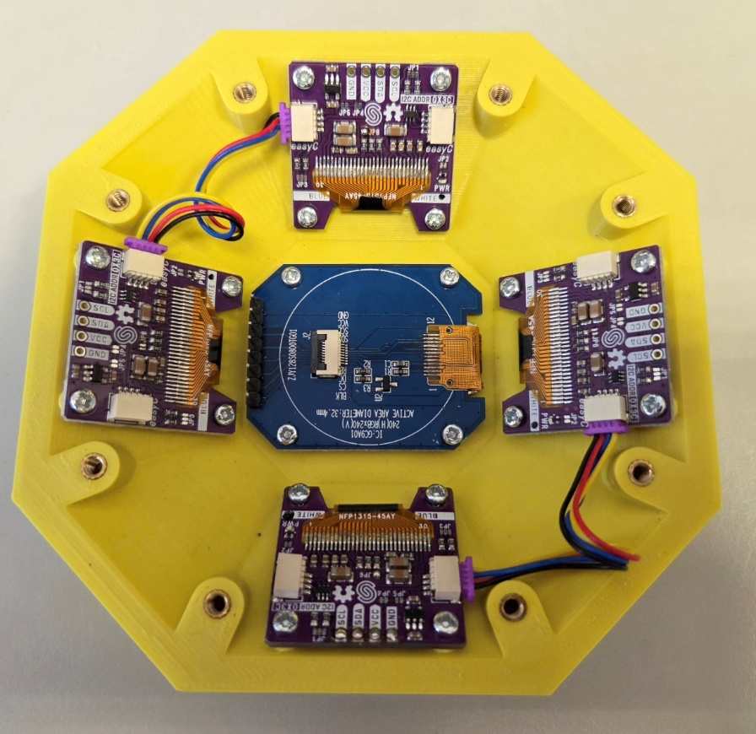
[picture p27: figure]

Use the remaining two 10cm 4-wire OLED cables and connect the one end as indicated:

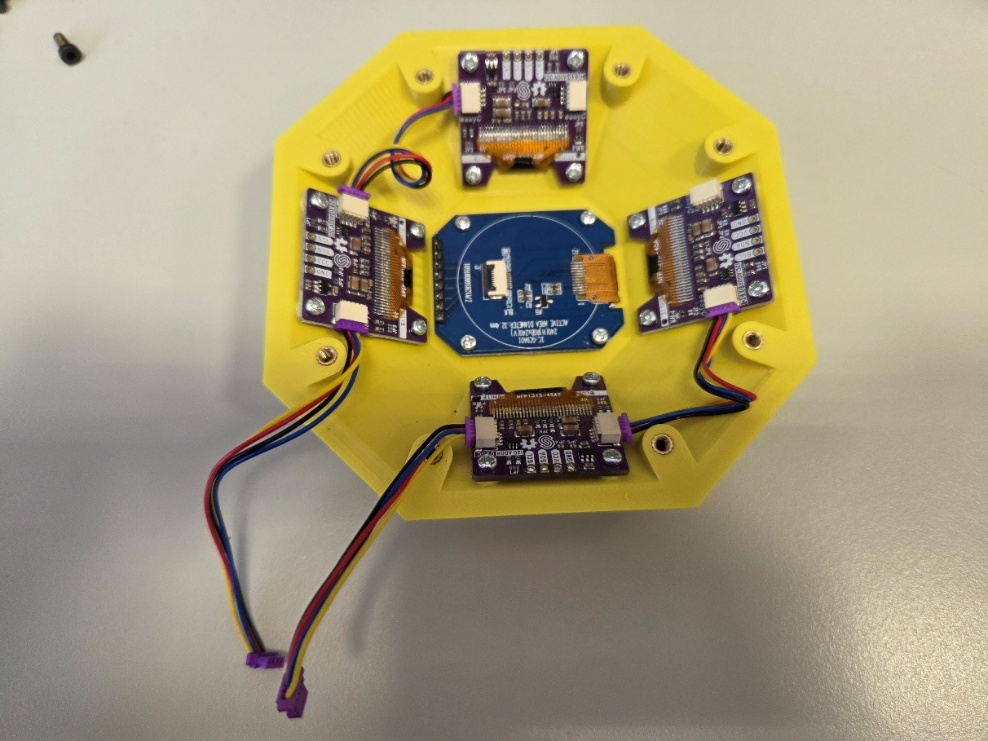
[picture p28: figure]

The final step of this wiring process is to connect 8x female to female jumper cables to the GC9A01 display:

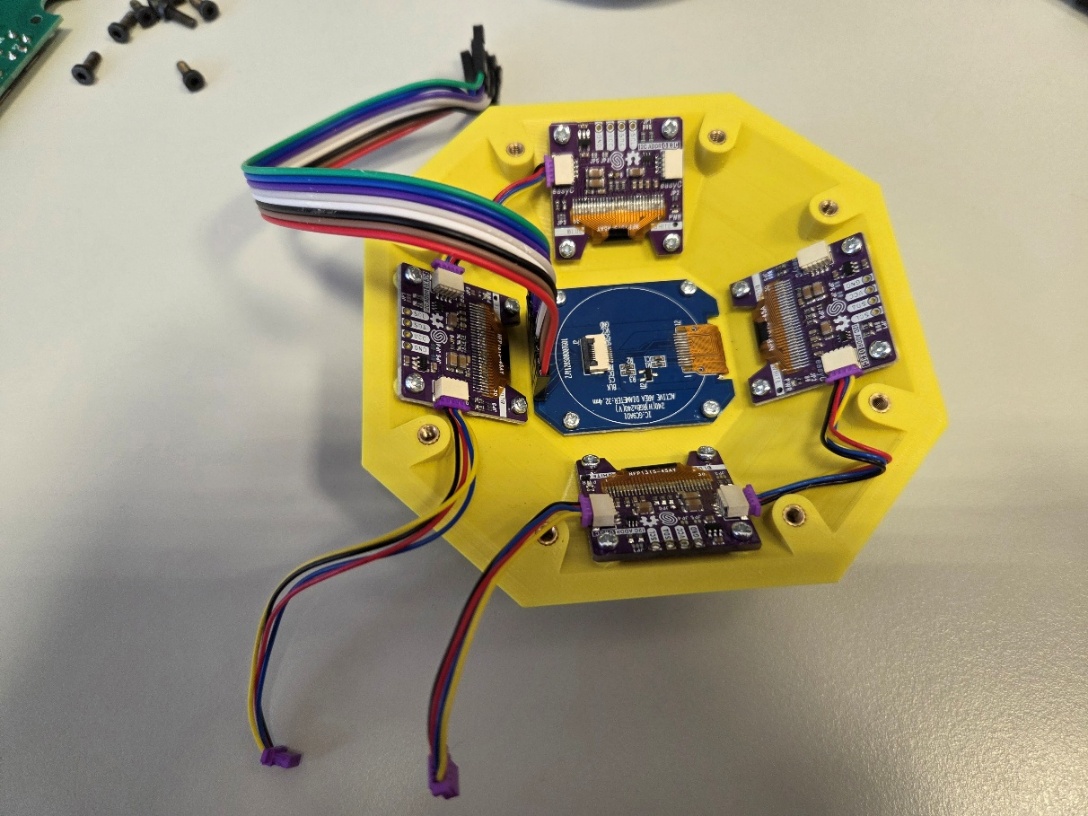
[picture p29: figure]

The rest of the wiring job will be done later.

9. Middle body part assembly

Tools and parts:

- Player buttons in 4 different colors
- 4x Field parts
- Middle body part
- 16x M2 screws
- 8x M3 HEX screws
- Screwdriver
- HEX screwdriver

Place the player buttons so that the yellow player is located at the bottom, red on the right side, blue at the top and green on the left side. Make sure that the order of the buttons is correct (left, confirm and right button).

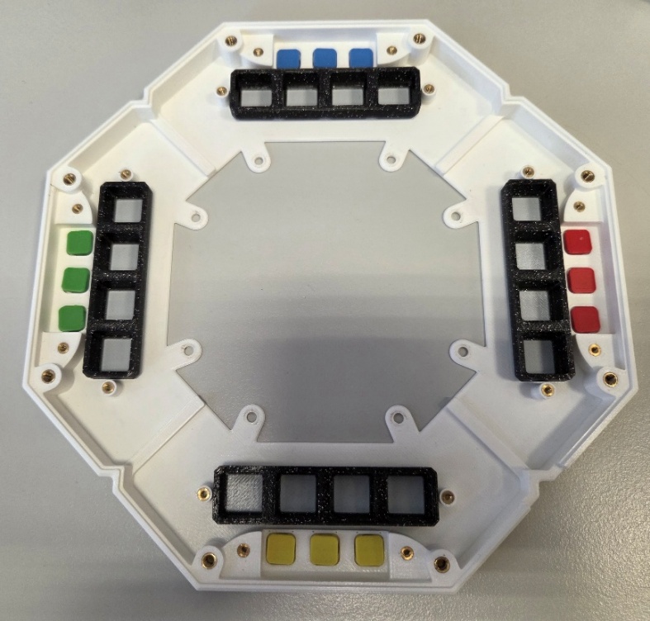
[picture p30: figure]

Place the 4 fields, one for each players:

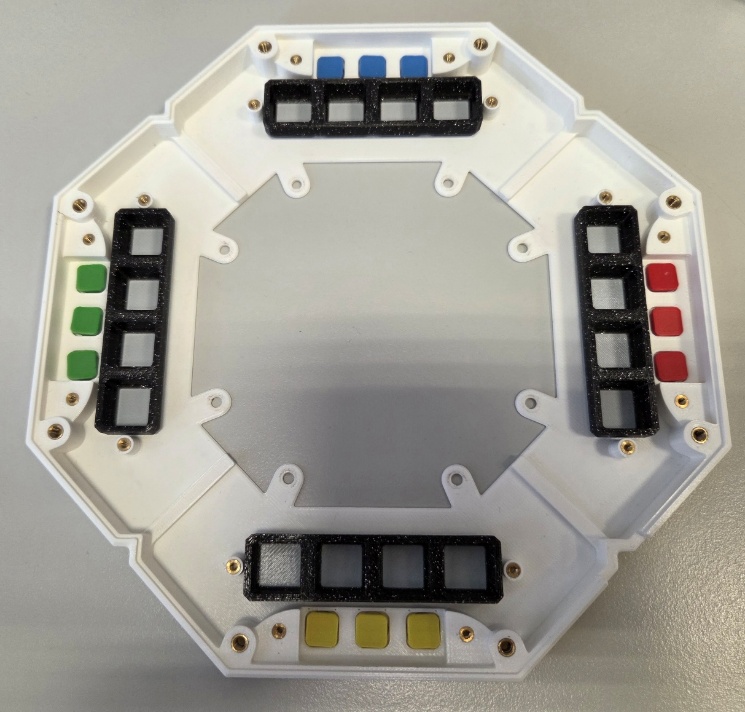
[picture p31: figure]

Assemble the upper and Middle body part of the FarmGame using 8 HEX screws.

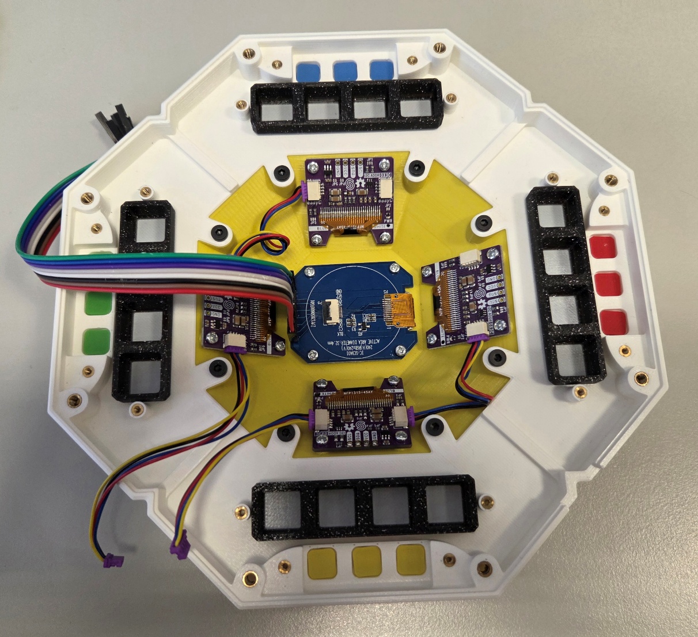
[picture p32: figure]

Next, it's time to mount the PCB to the middle body part. Carefully place the PCB on the bottom of the Middle body part and align the holes with threads without moving the previously placed buttons and Fields. Use the 16 M2 screws and screw them in. Try not to overtighten them.

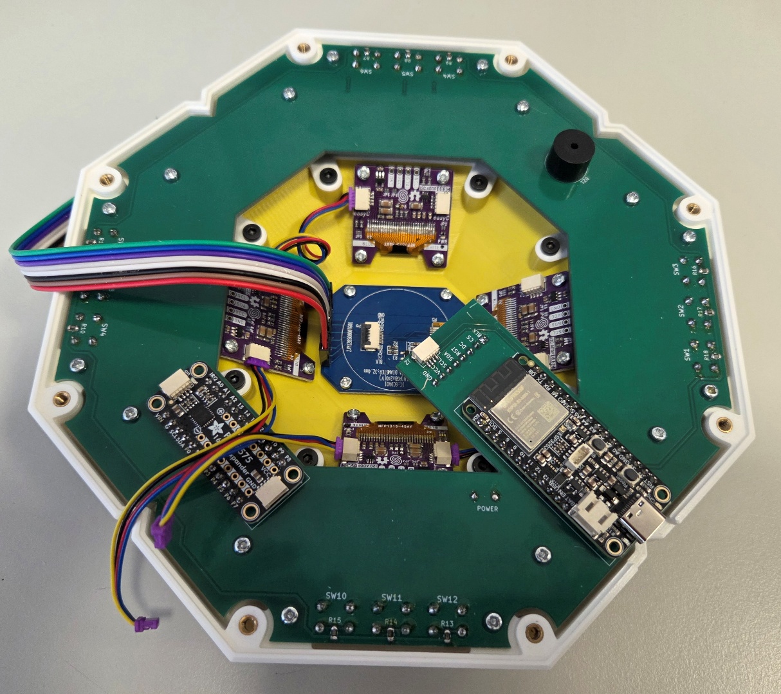
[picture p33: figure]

Test every push button if it works properly. If some of them are not going in or out smoothly, try to reduce the torque of closest screw and check again.

Now it's time to finish the wiring process. Connect the three 4-wire cables marked with yellow arrows. The GC9A01 8 pin wires need to be connected with caution (blue arrow). The bottom left wire on the GC9A01 display needs to be connected on the first (top) pin of the PCB, as shown in the following image:

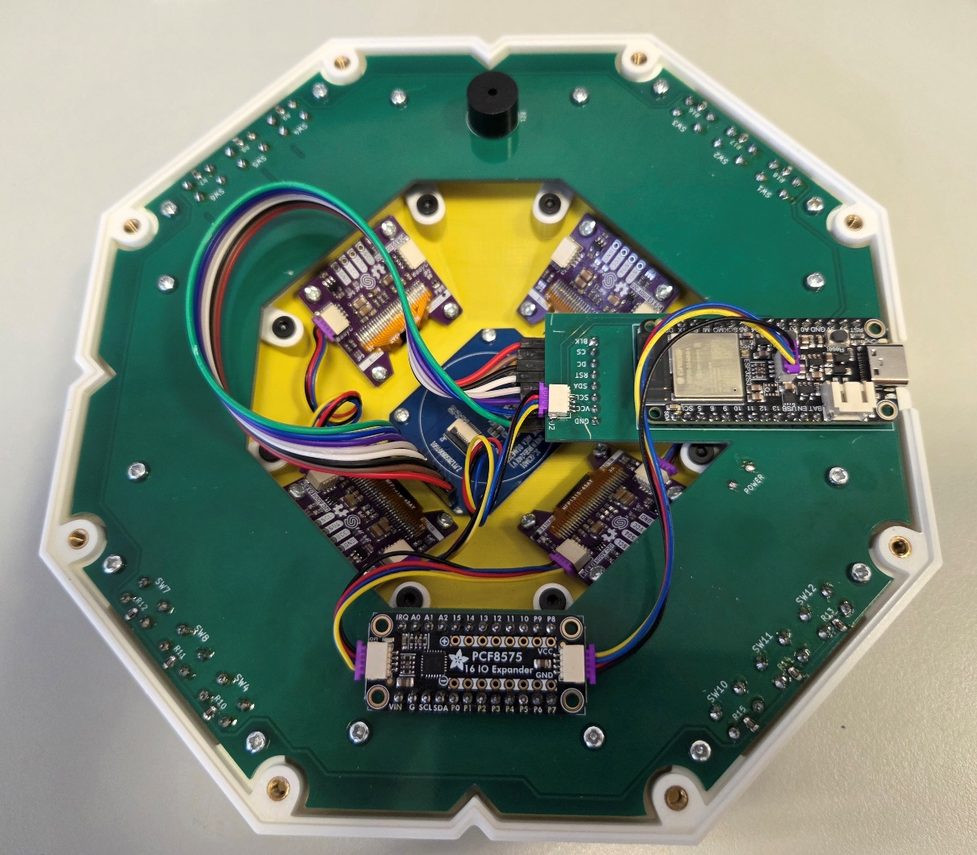
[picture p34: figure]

10. Bottom body part assembly

Parts and tools:

- 8x M3 HEX screws
- Bottom body part
- HEX screwdriver
- Rubber feet
- Battery
- Power switch and wires

Insert the power switch into the opening on the bottom housing, then solder the switch and the two wires to the PCB pads labeled “POWER” (indicated by the yellow arrow).

Secure the battery inside the bottom housing using the adhesive tape, and connect it to the microcontroller (as shown by the blue arrow).

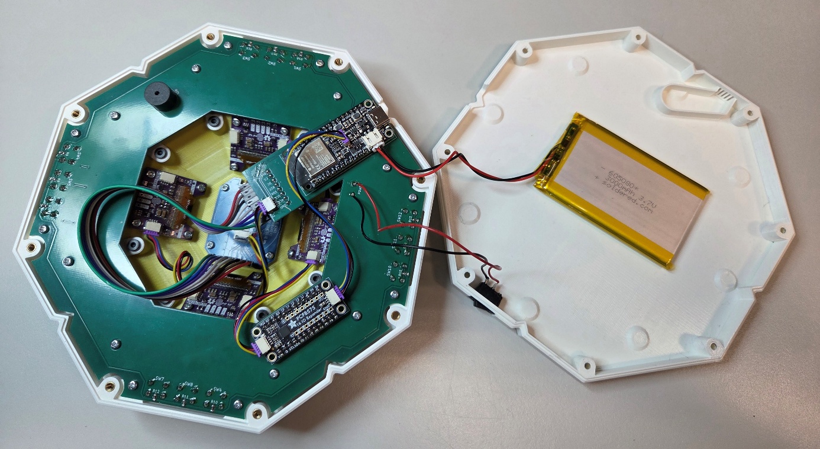
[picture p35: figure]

The Bottom body part is just a cover that is attached to the Middle body part using 8x M3 HEX screws. Align the Bottom body part so that the hole for USB cable is properly aligned.

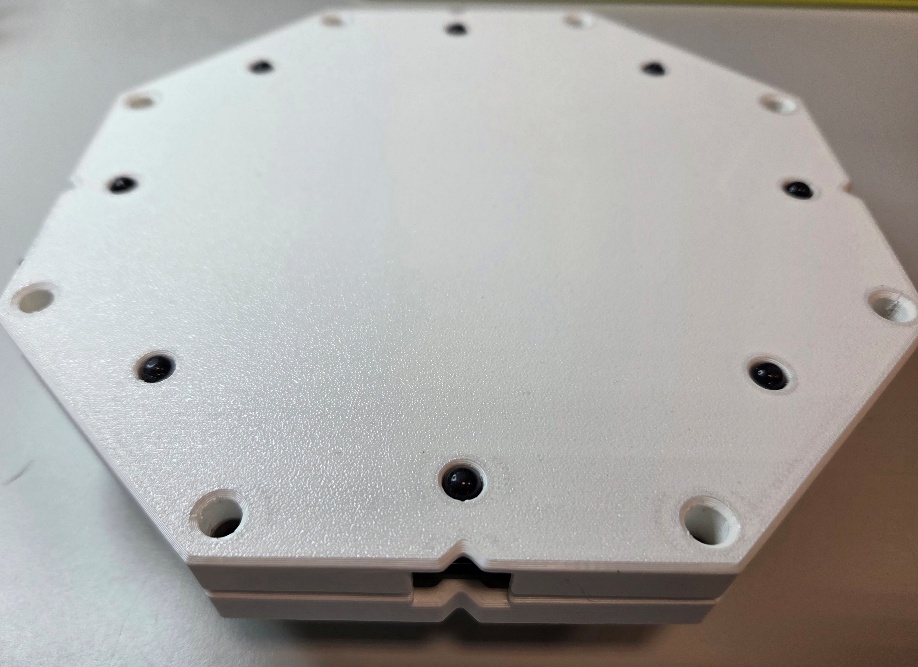
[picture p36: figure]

Use the hex screwdriver to tighten the M3 hex screws (indicated by the yellow arrow). Then attach the rubber feet (shown by the blue arrow).

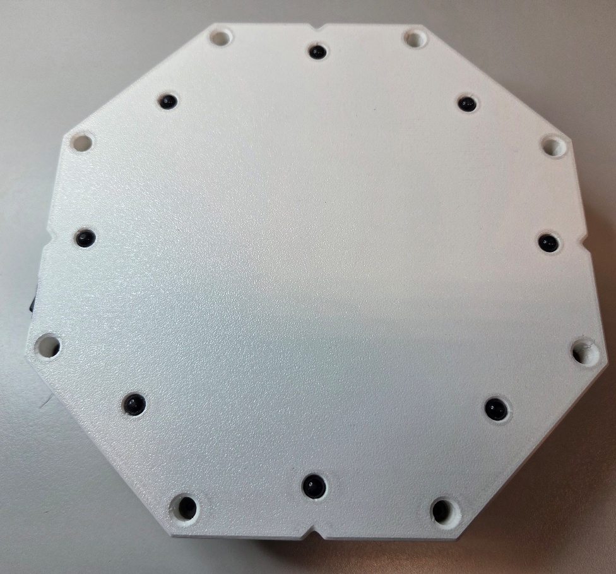
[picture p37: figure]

11. Flashing the device

Connect the FarmGame to the PC using the USB-C cable. Download the provided code from the repository and open the project file using Visual Studio Code with installed PlatformIO addon. Compile the code and flash the device.

You are done! The FarmGame will start and you can start testing it! Have fun!

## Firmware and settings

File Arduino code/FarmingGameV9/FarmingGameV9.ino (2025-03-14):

/*
 U ovoj verziji je dodana DUMMY LEDica 
*/

#include <SPI.h>
#include <TFT_eSPI.h> // Hardware-specific library
#include <Wire.h>
#include <Adafruit_GFX.h>
#include <Adafruit_SSD1306.h>
#include <Adafruit_NeoPixel.h>
#include <Ticker.h>
#include <PNGdec.h>
#include "images.h"
#include <sys/random.h>

#define NEOPIXEL_PIN        12
#define NUMPIXELS           17
#define SCREEN_WIDTH 128
#define SCREEN_HEIGHT 64
#define I2C_SDA 33
#define I2C_SCL 32
#define debug true
#define MAX_IMAGE_WIDTH 240 // Adjust for your images

#define NUMBER_OF_TURNS 7

#define CORN_TURNS 1
#define CARROT_TURNS 2
#define TOMATO_TURNS 2
#define LETTUCE_TURNS 3
#define BLUEBERRY_TURNS 4

#define CORN_POINTS 1
#define CARROT_POINTS 3
#define TOMATO_POINTS 4
#define LETTUCE_POINTS 5
#define BLUEBERRY_POINTS 7

int buttonPins[] = {4, 13, 16, 35, 36, 39, 26, 27, 34, 17, 18, 25};
bool previousState[] = {true, true, true, true, true, true, true, true, true, true, true, true};
bool currentState[] = {true, true, true, true, true, true, true, true, true, true, true, true};
bool P1Buttons[] = {false, false, false};
bool P2Buttons[] = {false, false, false};
bool P3Buttons[] = {false, false, false};
bool P4Buttons[] = {false, false, false};

TwoWire I2C_1 = TwoWire(0);
TwoWire I2C_2 = TwoWire(1);
Ticker readButtons;

PNG png; // PNG decoder instance

// Declaration for an SSD1306 display connected to I2C (SDA, SCL pins)
Adafruit_SSD1306 display1(SCREEN_WIDTH, SCREEN_HEIGHT, &I2C_1, -1);
Adafruit_SSD1306 display2(SCREEN_WIDTH, SCREEN_HEIGHT, &I2C_1, -1);

Adafruit_SSD1306 display3(SCREEN_WIDTH, SCREEN_HEIGHT, &I2C_2, -1);
Adafruit_SSD1306 display4(SCREEN_WIDTH, SCREEN_HEIGHT, &I2C_2, -1);

Adafruit_NeoPixel pixels(NUMPIXELS, NEOPIXEL_PIN, NEO_GRB + NEO_KHZ800);

TFT_eSPI tft = TFT_eSPI();       // Invoke custom library
Adafruit_SSD1306 display(SCREEN_WIDTH, SCREEN_HEIGHT, &Wire, -1);


uint8_t var2 = 1; //redni broj igrača
uint8_t pos;
uint8_t pos2;
uint8_t state = 0;
uint8_t state0Counter = 0;
uint8_t player1TurnCounter = 0;
uint8_t player2TurnCounter = 0;
uint8_t player3TurnCounter = 0;
uint8_t player4TurnCounter = 0;
bool printOnce = true;
bool player1Active = false;
bool player2Active = false;
bool player3Active = false;
bool player4Active = false;

bool players[] = {false, false, false, false};

bool generateWeatherOnce = true;

bool state0Started = false;
unsigned long startMillis;
unsigned long currentMillis;

struct playerStats {
  String weatherState;
  uint8_t points;
  String Field[4];
  int8_t FieldGrow[4];
};

playerStats player1 = {"", 0, {"corn", "empty", "empty", "empty"}, { 1, -1, -1, -1}};
playerStats player2 = {"", 0, {"corn", "empty", "empty", "empty"}, { 1, -1, -1, -1}};
playerStats player3 = {"", 0, {"corn", "empty", "empty", "empty"}, { 1, -1, -1, -1}};
playerStats player4 = {"", 0, {"corn", "empty", "empty", "empty"}, { 1, -1, -1, -1}};


void setup() {

  delay(500);
  Serial.begin(115200);

  //Tipkala INIT
  for (int i = 0; i < 12; i++) {
    pinMode(buttonPins[i], INPUT_PULLUP);
  }

  I2C_2.begin(I2C_SDA, I2C_SCL, 400000);

  if (!display1.begin(SSD1306_SWITCHCAPVCC, 0x3C)) { // Address 0x3D for 128x64
    Serial.println(F("SSD1306 allocation failed"));
    for (;;);
  }
  if (!display2.begin(SSD1306_SWITCHCAPVCC, 0x3D)) { // Address 0x3D for 128x64
    Serial.println(F("SSD1306 allocation failed"));
    for (;;);
  }
  if (!display3.begin(SSD1306_SWITCHCAPVCC, 0x3C)) { // Address 0x3D for 128x64
    Serial.println(F("SSD1306 allocation failed"));
    for (;;);
  }
  if (!display4.begin(SSD1306_SWITCHCAPVCC, 0x3D)) { // Address 0x3D for 128x64
    Serial.println(F("SSD1306 allocation failed"));
    for (;;);
  }

  // Read Buttons every 0.1s
  readButtons.attach(0.1, buttonsPressed);

  tft.init();
  tft.fillScreen(TFT_BLACK);

  display1.clearDisplay();
  display2.clearDisplay();
  display3.clearDisplay();
  display4.clearDisplay();

  pixels.setBrightness(255);
  pixels.begin(); // INITIALIZE NeoPixel strip object (REQUIRED)
  pixels.clear(); // Set all pixel colors to 'off'
  for ( int i = 0; i < NUMPIXELS; i++) {
    pixels.setPixelColor(i, 0, 0, 0);
  }
  pixels.show();
}

void buttonsPressed() {
  for (int i = 0; i < 12; i++) {
    currentState[i] = digitalRead(buttonPins[i]);
  }
  for (int i = 0; i < 12; i++) {
    if ((previousState[i] == true) && (currentState[i] == false)) {
      if (i < 3) {
        P1Buttons[i] = true;
      } else if ((i > 2) && (i < 6)) {
        P4Buttons[i - 3] = true;
      } else if ((i > 5) && (i < 9)) {
        P3Buttons[i - 6] = true;
      } else if (i > 8) {
        P2Buttons[i - 9] = true;
      }
    }
  }
  for (int i = 0; i < 12; i++) {
    previousState[i] = currentState[i];
  }
}

void state0 () {
  /* Print "Press to play" on displays
     10 sec countdown
     Print which players are active and which are not
  */

  if (!state0Started) {
    startMillis = millis();
    state0Started = true;
  }
  currentMillis = millis();

  if (!players[0]) {
    display1.clearDisplay();
    display1.setRotation(2); //rotacija za 180
    display1.setTextSize(2);
    display1.setTextColor(WHITE);
    display1.setCursor(20, 10);
    display1.println("Press");
    display1.drawBitmap(85, 7, confirmIcon, 20, 20, WHITE);
    display1.setCursor(20, 40);
    display1.println("to play");
    display1.display();
  } else {
    display1.clearDisplay();
    display1.setRotation(2); //rotacija za 180
    display1.setTextSize(2);
    display1.setTextColor(WHITE);
    display1.setCursor(30, 10);
    display1.println("Player");
    display1.setCursor(15, 40);
    display1.println("confirmed");
    display1.display();
  }
  if (!players[1]) {
    display2.clearDisplay();
    display2.setRotation(2); //rotacija za 180
    display2.setTextSize(2);
    display2.setTextColor(WHITE);
    display2.setCursor(20, 10);
    display2.println("Press");
    display2.drawBitmap(85, 7, confirmIcon, 20, 20, WHITE);
    display2.setCursor(20, 40);
    display2.println("to play");
    display2.display();
  } else {
    display2.clearDisplay();
    display2.setRotation(2); //rotacija za 180
    display2.setTextSize(2);
    display2.setTextColor(WHITE);
    display2.setCursor(30, 10);
    display2.println("Player");
    display2.setCursor(15, 40);
    display2.println("confirmed");
    display2.display();
  }
  if (!players[2]) {
    display3.clearDisplay();
    display3.setRotation(2); //rotacija za 180
    display3.setTextSize(2);
    display3.setTextColor(WHITE);
    display3.setCursor(20, 10);
    display3.println("Press");
    display3.drawBitmap(85, 7, confirmIcon, 20, 20, WHITE);
    display3.setCursor(20, 40);
    display3.println("to play");
    display3.display();
  } else {
    display3.clearDisplay();
    display3.setRotation(2); //rotacija za 180
    display3.setTextSize(2);
    display3.setTextColor(WHITE);
    display3.setCursor(30, 10);
    display3.println("Player");
    display3.setCursor(15, 40);
    display3.println("confirmed");
    display3.display();
  }
  if (!players[3]) {
    display4.clearDisplay();
    display4.setRotation(2); //rotacija za 180
    display4.setTextSize(2);
    display4.setTextColor(WHITE);
    display4.setCursor(20, 10);
    display4.println("Press");
    display4.drawBitmap(85, 7, confirmIcon, 20, 20, WHITE);
    display4.setCursor(20, 40);
    display4.println("to play");
    display4.display();
  } else {
    display4.clearDisplay();
    display4.setRotation(2); //rotacija za 180
    display4.setTextSize(2);
    display4.setTextColor(WHITE);
    display4.setCursor(30, 10);
    display4.println("Player");
    display4.setCursor(15, 40);
    display4.println("confirmed");
    display4.display();
  }

  if (currentMillis - startMillis >= 1000)  //test whether the period has elapsed
  {
    state0Counter++;

    if (state0Counter == 11) {
      tft.fillScreen(TFT_BLACK);

      //Sljedeći igrač na redu
      //var2 = 0;

      if (debug) Serial.print("Sljedeći igrač na redu: ");
      if (debug) Serial.println(var2);

      //number of players
      uint8_t var = 0;
      for ( int i = 0; i < 4; i++) {
        if (players[i]) var++;
      }

      if (debug) Serial.print("Ukupan broj igrača: ");
      if (debug) Serial.println(var);

      //global var2 => redni broj igrača na potezu
      //Ovdje treba odrediti koji igrač je aktivan
      for (int i = 0; i < 4; i++) {
        if (players[i]) {
          if (i == 0) player1Active = true;
          else if (i == 1) player2Active = true;
          else if (i == 2) player3Active = true;
          else if (i == 3) player4Active = true;
          if (debug) Serial.print("Aktivni igrač: ");
          if (debug) Serial.println(i + 1);
          break;
        }
      }

      if (var > 1) state = 4; //Weather
      else state = 6; //warning

      if (!players[0]) {
        display1.clearDisplay();
        display1.display();
      }
      if (!players[1]) {
        display2.clearDisplay();
        display2.display();
      }
      if (!players[2]) {
        display3.clearDisplay();
        display3.display();
      }
      if (!players[3]) {
        display4.clearDisplay();
        display4.display();
      }
    } else {
      tft.setRotation(2);
      tft.drawSmoothArc(tft.width() / 2, tft.height() / 2, 110, 80, 0, state0Counter * 36, TFT_WHITE, TFT_BLACK, true);
    }
    startMillis = currentMillis;  //IMPORTANT to save the start time of the current LED state.
  }

  //Polling the Confirm buttons
  if (P1Buttons[1]) {
    P1Buttons[1] = false;
    players[0] = true;
    if (debug) Serial.println("Player1 confirmed");
  }
  if (P2Buttons[1]) {
    P2Buttons[1] = false;
    players[1] = true;
    if (debug) Serial.println("Player2 confirmed");
  }
  if (P3Buttons[1]) {
    P3Buttons[1] = false;
    players[2] = true;
    if (debug) Serial.println("Player3 confirmed");
  }
  if (P4Buttons[1]) {
    P4Buttons[1] = false;
    players[3] = true;
    if (debug) Serial.println("Player4 confirmed");
  }
}

void weatherPhase() {

  if (player1Active) {

    if (generateWeatherOnce) {
      tft.setRotation(2);
      //Generate weather
      player1.weatherState = generateWeather();
      if (debug) Serial.print("The weather for player1 is ");
      if (debug) Serial.println(player1.weatherState);

      displayColors();

      display1.clearDisplay();
      display1.setTextSize(2);
      display1.setTextColor(WHITE);
      display1.setCursor(25, 5);
      display1.println("Weather:");

      if ( player1.weatherState != "drought" ) {
        for (int i = 0; i < 4; i++) {
          if (player1.FieldGrow[i] > 0)
            player1.FieldGrow[i] --;
        }
      }

      if ( player1.weatherState == "drought" ) display1.setCursor(25, 22);
      else if ( player1.weatherState == "sunny" ) display1.setCursor(32, 22);
      else if ( player1.weatherState == "rain" ) display1.setCursor(35, 22);

      display1.print(player1.weatherState);
      display1.drawBitmap(54, 40, confirmIcon, 20, 20, WHITE);
      display1.display();
      generateWeatherOnce = false;
    }
    if (P1Buttons[1]) {
      //Confirm
      state = 1;
      pos = 1;
      P1Buttons[1] = false;
      generateWeatherOnce = true;
      displayField();
    }
  } else if (player2Active) {

    if (generateWeatherOnce) {
      tft.setRotation(3);
      //Generate weather
      player2.weatherState = generateWeather();
      if (debug) Serial.print("The weather for player2 is ");
      if (debug) Serial.println(player2.weatherState);

      displayColors();

      display2.clearDisplay();
      display2.setTextSize(2);
      display2.setTextColor(WHITE);
      display2.setCursor(25, 5);
      display2.println("Weather:");

      if ( player2.weatherState != "drought" ) {
        for (int i = 0; i < 4; i++) {
          if (player2.FieldGrow[i] > 0)
            player2.FieldGrow[i] --;
        }
      }

      if ( player2.weatherState == "drought" ) display2.setCursor(25, 22);
      else if ( player2.weatherState == "sunny" ) display2.setCursor(32, 22);
      else if ( player2.weatherState == "rain" ) display2.setCursor(35, 22);

      display2.print(player2.weatherState);
      display2.drawBitmap(54, 40, confirmIcon, 20, 20, WHITE);
      display2.display();
      generateWeatherOnce = false;
    }
    if (P2Buttons[1]) {
      //Confirm
      state = 1;
      pos = 1;
      P2Buttons[1] = false;
      generateWeatherOnce = true;
      displayField();
    }
  } else if (player3Active) {

    if (generateWeatherOnce) {
      tft.setRotation(0);
      //Generate weather
      player3.weatherState = generateWeather();
      if (debug) Serial.print("The weather for player3 is ");
      if (debug) Serial.println(player3.weatherState);

      displayColors();

      display3.clearDisplay();
      display3.setTextSize(2);
      display3.setTextColor(WHITE);
      display3.setCursor(25, 5);
      display3.println("Weather:");

      if ( player3.weatherState != "drought" ) {
        for (int i = 0; i < 4; i++) {
          if (player3.FieldGrow[i] > 0)
            player3.FieldGrow[i] --;
        }
      }

      if ( player3.weatherState == "drought" ) display3.setCursor(25, 22);
      else if ( player3.weatherState == "sunny" ) display3.setCursor(32, 22);
      else if ( player3.weatherState == "rain" ) display3.setCursor(35, 22);

      display3.print(player3.weatherState);
      display3.drawBitmap(54, 40, confirmIcon, 20, 20, WHITE);
      display3.display();
      generateWeatherOnce = false;
    }
    if (P3Buttons[1]) {
      //Confirm
      state = 1;
      pos = 1;
      P3Buttons[1] = false;
      generateWeatherOnce = true;
      displayField();
    }
  } else if (player4Active) {

    if (generateWeatherOnce) {
      tft.setRotation(1);
      //Generate weather
      player4.weatherState = generateWeather();
      if (debug) Serial.print("The weather for player4 is ");
      if (debug) Serial.println(player4.weatherState);

      displayColors();

      display4.clearDisplay();
      display4.setTextSize(2);
      display4.setTextColor(WHITE);
      display4.setCursor(25, 5);
      display4.println("Weather:");

      if ( player4.weatherState != "drought" ) {
        for (int i = 0; i < 4; i++) {
          if (player4.FieldGrow[i] > 0)
            player4.FieldGrow[i] --;
        }
      }

      if ( player4.weatherState == "drought" ) display4.setCursor(25, 22);
      else if ( player4.weatherState == "sunny" ) display4.setCursor(32, 22);
      else if ( player4.weatherState == "rain" ) display4.setCursor(35, 22);

      display4.print(player4.weatherState);
      display4.drawBitmap(54, 40, confirmIcon, 20, 20, WHITE);
      display4.display();
      generateWeatherOnce = false;
    }
    if (P4Buttons[1]) {
      //Confirm
      state = 1;
      pos = 1;
      P4Buttons[1] = false;
      generateWeatherOnce = true;
      displayField();
    }
  }
}
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
void loop() {

  //Player confirm if they want to play
  if (state == 0) state0();
  else if (state == 4) weatherPhase();
  else if (state == 1) harvestPhase();
  else if (state == 2) plantPhase();
  else if (state == 3) crops();
  else if (state == 5) gameEnded();
  else if (state == 6) playerWarning();
  else if (state == 7) allPlayersDone();

}

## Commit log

2024-10-29 Create Display OLED I2C White 0.96 SSD1306 3D.step
    [Display OLED I2C White 0.96 SSD1306 3D.step]
2025-03-05 3D model
    [FullPCB.step]
2026-05-06 V3 files
    [BottomBodyPart.3mf, BottomBodyPart.stl, Button - Confirm.stl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]
